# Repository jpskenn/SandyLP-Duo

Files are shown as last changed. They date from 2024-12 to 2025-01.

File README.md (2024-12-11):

# SandyLP Duo（サンディ エルピー デュオ）

![SandyLP Duo keyboard]()  

"SandyLP Duo" is a Split 40% keyboard with symmetrical row staggered layout and key height optimization.

Layered PCB will make height differences for each key.
This covers the lack of optimization to physical key layout in two dimensions that only adjust x-y plane.

---

SandyLP Duoは、スイッチの配置を立体的にして高さ方向への最適化を加えた、左右対称ロースタッガード配列の分割型40%キーボードです。  

平面上のキーレイアウトだけでは最適化しきれない部分を、キーの位置に応じてスイッチを配置する高さを変えることで補っています。

開発の元となった[SandyLP](https://github.com/jpskenn/SandyLP)の機能や特徴を踏襲しつつ、肩や腕を開いたより自然なポジションでの打鍵と、テンティングによる手首や腕の負荷軽減を目指しています。

SandyLPのコンセプトをそのまま引きついだバリエーションモデルとして、分割型の特徴である左右ふたつのペアを思わせる言葉の「Duo」を後ろにつけ、「SandyLP Duo」としました。  
元の元であるSandyから説明すると、スイッチを立体的（3D）に配置したキーボードの、ロープロファイル版、分割型バリエーションモデルということになります。

## 特徴

### 分割型

見てのとおり、右手用と左手用のふたつに分かれた、分割型キーボードです。
右手用または左手用のどちらかをPCやMacに接続し、もう一方へUSB Type-Cケーブルで接続します。

右手用と左手用を好みの場所に配置し、好みのポジションで打鍵できます。
前作の一体型キーボードSandyLP（中央部に2u分の間隔）に比べ、肩や腕を大きく開いたポジションをとることが可能で、肩や腕の負荷軽減が見込まれます。

また、ゴム足等を使ったテンティング（キーボードの内側を持ち上げて、親指側と小指側の高さを変える）をおこなうことで、手首や腕の負荷軽減が見込まれます。

### 左右対称のキーレイアウト  

[Jones](https://github.com/jpskenn/Jones)と同様の、2行目と3行目にずれのない、左右対称なシンメトリカル ロースタッガードのレイアウトです。  
左右対称のキーレイアウト

一般的なロースタッガードなレイアウトとの共通性を残しつつ、左右対称で打鍵しやすくなるよう、[SemiErgo Layout](https://github.com/mtei/SemiErgo_Layout)に準ずるキーマッピングで使用することを念頭に設計しています。  
Z行の左右端にシフトキーを用意していないので、スペースキーを「Space and Shift」として使うと便利です。

このレイアウトは、市販の各種キーキャップセットのうち「Base Kit」と呼ばれる基本的なキットですべてを埋めることができます。また、104キーの英語キーキャップセットでも十分実用が可能です。
〓Base Kitと104の検証
左右対称のキーレイアウト

詳しくは、[Keyboard Layout Editor: SandyLP Duo]()を参照してください。

### キースイッチを立体的に配置  

前機種の[Sandy](https://github.com/jpskenn/Sandy)と同じく、キースイッチを3段階の高さで立体的に配置しています。  
平面上ではキーを配置できる範囲が限られるため、一部のキーはどうしても指が届きにくくなってしまいます。例えば、[Jones](https://github.com/jpskenn/Jones)では左右対称のレイアウトを採用することで右手小指の`P`や`Back Space`、`Enter`などは打鍵しやすくなりましたが、右手人差し指の`Y`は少し遠く感じられました。  
このような箇所について、キーの配置を高くすることで打鍵しやすさを向上させています。  

キースイッチの高さ（中央部分）
キースイッチの高さ（横から）

キーの高さはLow（基準高＝0mm）, Middle（3.6mm）, High（8.7mm）の3段階で、以下のように配置されます。  
キーの高さ

### キーボード自体が低い（薄い）  

ロープロファイルの`Choc V2`スイッチを採用することでキーボード自体が低くなりました。  
前機種のSandyからは7.2mm（※1）低くなり、パームレストを使わずとも、手首をあまり反らさないポジションで打鍵できます。

※1 ボトムプレートから1段目のスイッチ軸の天面までの高さを比較。なお、Sandyは理論上あと0.8mm低くすることが可能です。

キースイッチの高さ

### RP2040を採用した構成により、多機能なファームウェアを使用可能

RP2040を採用した構成により、キーボード向けのファームウェアを格納するには十分すぎるほどのフラッシュ容量を得ることができました。  
エンコーダーやオーディオ、その他各種機能の同時有効化や、多数のレイヤーを使用するなど、多機能なファームウェアを使用可能です。

### Remap、Vialによるキー割り当ての変更  

初期書き込み済みのファームウェアは[Remap](https://remap-keys.app/)に対応しており、プログラミング等の知識がなくても、キーマッピングやロータリーエンコーダへの割り当てを、ブラウザ等を使って簡単に変更できます。  

また、Vial対応のファームウェアに書き換えて使用することもできます。

### オプション機能  

- ロータリーエンコーダ
- インジケータLED
- オーディオ

## ビルドガイド

## SNSタグ

[#SandyLP_Duo](https://twitter.com/search?q=%23SandyLP_Duo)

## ギャラリー

## 参考事例

## 開発経緯

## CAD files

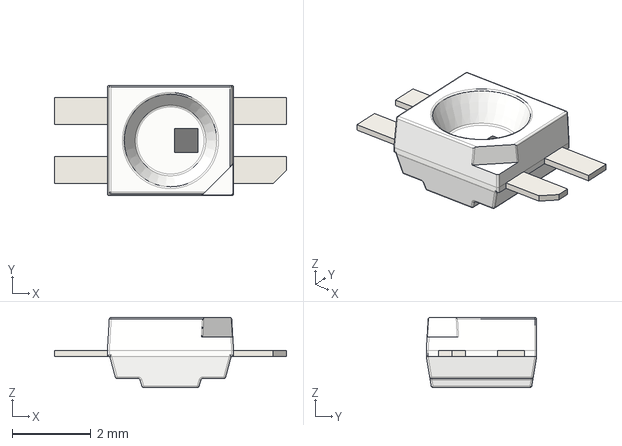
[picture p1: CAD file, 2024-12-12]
PCB/SandyLPD_Plate_BottomB/lib_LED/LED_SK6812MINI-E.step
5.88 x 2.80 x 1.78 mm

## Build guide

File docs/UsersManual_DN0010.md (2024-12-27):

# SandyLP Duo（DN0010）ユーザーズマニュアル

このドキュメントは、SandyLP Duo（DN0010）の組み立てや使用方法についてまとめたユーザーズマニュアルです。

組み立てや使用の前に[注意事項](#注意事項)をお読みください。

また、正しい使用方法の理解や各種トラブルの防止のため、早い時期に一通りお読みになることをお勧めします。

SandyLP Duoのコンセプトや特徴、ビルド例などについては、こちらの[README](https://github.com/jpskenn/SandyLP-Duo/blob/main/README.md)をご覧ください。

## 目次

<!-- @import "[TOC]" {cmd="toc" depthFrom=1 depthTo=3 orderedList=false} -->

<!-- code_chunk_output -->

- [SandyLP Duo（DN0010）ユーザーズマニュアル](#sandylp-duodn0010ユーザーズマニュアル)
  - [目次](#目次)
  - [注意事項](#注意事項)
  - [ビルドガイド](#ビルドガイド)
    - [部品リスト](#部品リスト)
    - [組み立てに使用する工具](#組み立てに使用する工具)
    - [組み立て手順](#組み立て手順)
  - [カスタマイズガイド](#カスタマイズガイド)
    - [初期ファームウェアの機能と設定値](#初期ファームウェアの機能と設定値)
    - [SandyLP Duo関連ファイル](#sandylp-duo関連ファイル)
    - [ファームウェアを書き換える](#ファームウェアを書き換える)
    - [EEPROMを消去して初期状態に戻す](#eepromを消去して初期状態に戻す)
    - [電源LEDを点灯しないようにする](#電源ledを点灯しないようにする)
    - [キーキャップの選び方](#キーキャップの選び方)
  - [サービスマニュアル](#サービスマニュアル)
    - [パーツリスト](#パーツリスト)
    - [基板セットアップ](#基板セットアップ)

<!-- /code_chunk_output -->

## 注意事項

〓TODO
〓ここには、基本的にクリティカルな何かだけ書くようにする。
〓場合によって、基板上のエラッタ的なものも記載。

## ビルドガイド

SandyLP Duo（DN0010）を組み立てる手順を説明します。

カッコ内の`DN0010`は開発番号を表しており、各基板のうら側に記載されています。  
<small>（外観上の理由により、リバーシブルのスイッチプレートには記載していません。）</small>
開発ナンバー

[組み立て手順](#組み立て手順)に一通り目を通してから作業を始めると、ミスの防止につながります。

### 部品リスト

このキーボードを組み立てて完成させるためには、[キット内容](#キット内容)に加え、[別途用意が必要な部品](#別途用意が必要な部品)が必要です。  

[オプション部品](#オプション部品)は無くても完成させることができます。  
使いたい機能に応じて用意してください。  

#### キット内容

このキットに同梱されている部品等の内容です。  

| 部品名 | 個数 | 備考 |
| :-- | :--: | :-- |
| ご案内リーフレット | 1 | |
| 基板Base（ひだり） | 1 | 多数の部品を取り付け済み。 |
| 基板Base（みぎ） | 1 | 多数の部品を取り付け済み。 |
| 基板Mid内側（ひだり・みぎ） | 2 | 同一形状の2枚を、左用、右用として使用。 |
| 基板Mid外側 （ひだり・みぎ）| 2 | 同一形状の2枚を、左用、右用として使用。 |
| 基板Top （ひだり・みぎ）| 2 | 同一形状の2枚を、左用、右用として使用。 |
| Base用スイッチプレート（ひだり・みぎ） | 2 | 同一形状の2枚を、左用、右用として使用。 |
| Mid内側用スイッチプレート（ひだり・みぎ） | 2 | 同一形状の2枚を、左用、右用として使用。|
| Mid外側用スイッチプレート（ひだり・みぎ） | 2 | 同一形状の2枚を、左用、右用として使用。 |
| Top用スイッチプレート（ひだり・みぎ） | 2 | 同一形状の2枚を、左用、右用として使用。 |
| ボトムプレートA | 2 | 〓未定 |
| ボトムプレートB | 2 | 同一形状の2枚を、左用、右用として使用。 |
| スペーサー<br>中空 M2 3.5mm | 6 | [CB-2003.5E](https://hirosugi.co.jp/products/B/CB-E.html#bx3) |
| 長いスルーホールタップ<br>M2 2mm | 22 | [THC-0.8-2.0-2](https://www.mac8sdk.co.jp/products/713) |
| 短いスルーホールタップ<br>M2 1mm | 22 | [THC-0.8-1.0-2](https://www.mac8sdk.co.jp/products/713) |
| 長いねじネジ<br>M2 8mm | 6 | [F-0280N-03](https://wilco.jp/products/F/F-N-03.html#page3) |
| 短いネジ<br>M2 3mm | 16 | [F-0230N-02](https://wilco.jp/products/F/F-N-02.html#page3) |
| 長いプラネジ<br>M2 5mm | 16 | [PC-0205](https://wilco.jp/products/PC/PC.html#page2) |
| 短いプラネジ<br>M2 3mm | 12 | [PC-0203](https://wilco.jp/products/PC/PC.html#page2) |
| ゴム足 | 4 | 〓半球っぽいやつにしたい |
| USBコネクタキャップ | 1 | 出荷時は`基板Base（みぎ）`へ取り付け済み。[TK-CAP6W](https://www.yodobashi.com/product/100000001003693842/) |
| ダイオード<br>1N4148W SOD123 | 15 | 予備3個含む。<br>[1N4148W](https://akizukidenshi.com/catalog/g/g107084/) |
| LED<br>WS2812C-2020 | 6 | [WS2812C-2020](https://akizukidenshi.com/catalog/g/g115068/) |
| Chocスイッチ用ソケット | 50 | 予備4個含む。<br>[Kailh Switch Socket（Kailh Choc ロープロファイル用）](https://shop.yushakobo.jp/products/a01ps?variant=37665172553889) |
| ゴムシート<br>T=1mm 10mm * 500mm | 〓使用本数未定 | [低弾性ゴムシート－ハネナイトＲ](https://jp.misumi-ec.com/vona2/detail/110300277050/?ProductCode=UNLEA1-10) |
| ポロンシート<br>T=1.5mm 50mm * 〓50mm幅で何mm | 1 | [イノアック L32-1.550-MT マイクロセルウレタンロールPORON 黒 1.5×50mm×1M巻](https://www.yodobashi.com/product/100000001004002516/) |

※備考欄には入手性のよい製品を記載しています。出荷時期によって機能的に同等なものへ変更することがあります。

基板  
〓左上から時計回りに、基板Top、基板Mid中央、基板Mid左右（2枚）、基板Base。  
〓基板  

プレート類  
〓左上から時計回りに、Top用スイッチプレート、Mid中央用スイッチプレート、Mid左右用スイッチプレート（2枚）、Base用スイッチプレート、ボトムプレート。  
〓プレート類  

〓その他部品  
〓その他部品  
〓ネジとかは乗せなくても良いけど、ゴムシートは見分けがつきにくいので、写真を載せる。

#### 別途用意が必要な部品

完成させるには、キット内容とは別に、以下の部品を用意する必要があります。

| 部品名 | 個数 | 備考 |
| :-- | :--: | :-- |
| Choc V2スイッチ | 46 | ロータリーエンコーダを取り付ける場合は、その分だけスイッチの取り付け数が減ります。<br>Choc V1スイッチは、固定ピンがないもの、または固定ピンを取り外したものであれば取り付け可能です。<br>ピンが折れたりした場合に備えて少し多めに買っておくとよいでしょう。 |
| キーキャップ<br>Choc V2スイッチ用 | 必要数 | GMKやePBT等のいわゆるBase Kitを使用すると、良い具合に仕上げることが可能です。<br>一部のMXスイッチ用のキーキャップは、組み合わせによってはスイッチプレートやスイッチに干渉する場合があります。<br>詳しくは[キーキャップの選び方](#キーキャップの選び方)を参照してください。 |
| USBケーブル （Type-C） | 1 | コンピュータ等への接続に使用します。Type-C to Type-Cや、Type-C to Type-Aなどを用意してください。<br>Base基板に取り付けられているコネクタはType-Cです。 |
| USBケーブル （Type-C to Type-C） | 1 | 左右のデバイス間通信に使用します。 |

#### オプション部品

オプション部品は無くてもかまいません。  
使いたい機能に応じて用意します。

| 部品名 | 個数 | 備考 |
| :-- | :--: | :-- |
| DIPスイッチ | 2 | [表面実装DIPスイッチ 4P](https://akizukidenshi.com/catalog/g/g108929/) |
| ロータリーエンコーダ<br>ALPS EC11, EC12同等品 | 1 | ロータリーエンコーダを使用する場合。<br>プッシュスイッチ付きにも対応。 |
| ロータリーエンコーダ用ノブ（つまみ） | 1 | ロータリーエンコーダを使用する場合。 |
| スピーカー<br>Murata PKMCS0909E4000-R1 | 〓2 | [PKMCS0909E4000-R1](https://www.digikey.jp/ja/products/detail/murata-electronics/PKMCS0909E4000-R1/4878400) |

### 組み立てに使用する工具

こちらの[工具セット](https://shop.yushakobo.jp/products/a9900to)などを参考に工具を用意します。

- 必要な工具

  - 先の細いプラスドライバー

    M2ネジに対応する「#0」など。

  - はんだ付け関連用品

    はんだ、はんだごて（温度調整機能つきを推奨）、こて台、ピンセットなど。  
    小さな部品のはんだ付けや、ちょっとした修正、取り外しなどの作業がしやすくなるので、フラックスやハンダ吸い取り線もあると良いでしょう。

  - はさみ または カッター
    ゴムシートの切断に使用。

- あると便利な工具

  - マジックペン

    基板の側面を塗ると、完成時の質感が上がります。  
    暗めの色を塗る場合は[プロッキー](https://www.mpuni.co.jp/products/felt_tip_pens/water_based/sign_pen/prockey.html)を、明るめの色を塗る場合は不透明顔料インクの[ポスカ](https://www.mpuni.co.jp/products/felt_tip_pens/water_based/posca/standard.html)を使うなど、お好みで。

  - テスター  
    はんだ付けの確認作業や、何か不具合があった場合の原因調査で活躍します。

### 組み立て手順

手順に沿って、順番に組み立てます。

- 【こだわり作業】の手順は、完成時の質感を重視した内容であり、不要であれば作業をとばしてもかまいせん。

- 【該当者のみ】の手順は、条件に該当する場合のみ作業します。

- みぎ側とひだり側、おもて側とうら側を間違えないよう、基板の表記を確認しながら作業を進めます。

    左右の表記  
    左右の表記

    うら側の表記  
    Back Sideの表記

#### 組み立て前の確認

出荷前に基本的な動作確認を実施済みですが、輸送時の破損なども考えられるため、組み立てを始める前に動作確認をおこないます。  
確認結果に問題がある場合は、リーフレットに記載の連絡先へ相談してください。

##### 基板BaseがPCやMacで認識されるかを確認する

1. `基板Base（ひだり）`を用意し、基板のうら側を上にして安定した場所へ置く。

1. `Computer`と書かれたUSBコネクタへケーブルを差し込み、PCやMacに接続する。

1. 基板うら側の電源LED〓`STLED`が緑色に点灯することを確認する。

1. PCやMacで、キーボードとして認識されていることを確認する。  
    確認例：
    - Windows 11  
    設定 → Bluetoothとデバイス → デバイス → 入力  
    「sandy_lpd」が表示されていること。

    - Mac  
    システムレポート → USB  
    「sandy_lpd」が表示されていること。

1. 確認出来たら、USBケーブルを抜く。

1. `基板Base（みぎ）`についても、同様の確認をおこなう。

    💡ヒント：出荷時は`基板Base（みぎ）`の`Computer`と書かれたUSBコネクタにキャップが取り付けられています。キャップを外して確認します。  

1. USBコネクタにキャップを取り付ける。

    確認が終わったら、普段使わない方の`Computer`と書かれたUSBコネクタにキャップを取り付け、誤って同時接続しないようにします。

##### 基板Baseの反応を確認する

1. `基板Base（ひだり）`と`基板Base（みぎ）`を用意し、それぞれの基板の`Keyboard`と書かれたUSBコネクタへケーブルを差し込み、左右を接続します。

1. 左右いずれかの`Computer`と書かれたUSBコネクタへケーブルを差し込み、PCやMacに接続します。

    左右の基板うら側の電源LEDが緑色に点灯することを確認する。

1. [Remap（https://remap-keys.app/）](https://remap-keys.app/)を、対応するブラウザ（ChromeやEdgeなど）で開く。

1. `CUSTOMIZE YOUR KEYBOARD`ボタンを押す。

1. `+ KEYBOARD`を押す。

1. ポップアップ画面で`sandy_lpd`を選択して、`接続`を押す。  

1. 画面にキーボードのレイアウトが表示されるまでしばらく待つ。

    30秒待っても表示されないときは、ブラウザをリロードしてやり直します。

1. キーボードのレイアウトの右側の一番下にある`…`をクリックして、表示されたメニューから`Test Matrix Mode`を選択する。

1. キースイッチの反応を確認する。

    基板うら側のスイッチソケット取り付け用パッド（銀色の四角い端子部分）をピンセットなどでショートさせ、ブラウザ画面上の対応するキーの色が変わることを確認します。

    スイッチ取り付け用パッド

    すべてのパッドで実施した後、以下のように色が変われば正常です。  
    基板Base確認結果

#### 【こだわり作業】基板とスイッチプレート側面をマジックで塗る

完成時の質感を高めるため、すべての基板とスイッチプレート、ボトムプレートの側面をマジックで塗ります。

💡ヒント：組み立て後は、スイッチを取り外したりネジを外して分解したりしないと塗れなくなる箇所があります。後からやるのは大変なので、どうせなら、この段階でやってしまった方が楽です。

#### 部品のはんだ付け

##### 基板Topへのはんだ付け

1. `基板Top（ひだり・みぎ）`の2枚を、うら側が見えるように置く。

    片方は「Left 左 Back Side」、もう片方は「Right 右 Back Side」と書かれた面が見えるようにします。

1. うら側から、`ダイオード`を取り付ける。（左右それぞれ1個）

    `基板Top（ひだり）`は`D1`へ、  
    `基板Top（みぎ）`は`D2`へ取り付けます。  〓Dの番号？
    取り付け位置

    基板のダイオード用パッド2個のうち、片方のパッドに予備はんだ（はんだを少しだけつけておく）します。  
    基板に描かれた枠のうち、短辺が閉じている方向（▲マークが示す先の少し太い線がある方向）にダイオードの印を合わせ、予備はんだしたところへ、ダイオードの端子をはんだ付けします。  
    片方を固定できたら、もう一方の端子をはんだ付けします。  
    ダイオードの方向

1. うら側から、`Chocスイッチ用ソケット`を取り付ける。（左右それぞれ1個）

    基板に描かれた枠に合わせてソケットを置きます。  

    💡ヒント：Chocスイッチ用ソケットは、取り付ける方向が決まっています。参考：[Kailh Choc ソケットの方向について](https://scrapbox.io/self-made-kbds-ja/Kailh_Choc_ソケットの方向について)

    Chocスイッチ用ソケットの方向

    ダイオードを取り付けた時と同様に、片方のパッドに予備はんだして取り付けます。
    ソケットが基板にぴったりと接するように、プラ部分をピンセットで押さえながらはんだ付けするとよいでしょう。

    取り付け位置

1. `基板Top（ひだり・みぎ）`の2枚を、おもて側が見えるように置く。

    先ほど取り付けた部品が下側になるように、基板をひっくり返します。

1. おもて側から、`短いスルーホールタップ`を取り付ける。（左右それぞれ2個）

    `基板Top（ひだり）`は`〓`へ、  
    `基板Top（みぎ）`は`〓`へ取り付けます。

##### 基板Mid内側へのはんだ付け

1. `基板Mid内側（ひだり・みぎ）`の2枚を、うら側が見えるように置く。

    片方は「Left 左 Back Side」、もう片方は「Right 右 Back Side」と書かれた面が見えるようにします。

1. うら側から、`ダイオード`を取り付ける。（左右それぞれ3個）

    `基板Top（ひだり）`は`D1`...`D3`へ、  
    `基板Top（みぎ）`は`D4`...`D6`へ取り付けます。  〓Dの番号？  
    取り付け位置

1. うら側から、`Chocスイッチ用ソケット`を取り付ける。（左右それぞれ3個）

    取り付け位置

1. `基板Mid内側（ひだり・みぎ）`の2枚を、おもて側が見えるように置く。

1. おもて側から、`短いスルーホールタップ`を取り付ける。（左右それぞれ2個）

    `基板Top（ひだり）`は`D1`...`D3`へ、  
    `基板Top（みぎ）`は`D4`...`D6`へ取り付けます。  〓Holeの番号？  

##### 基板Mid左右へのはんだ付け

1. `基板Mid外側（ひだり・みぎ）`の2枚を、うら側が見えるように置く。

    片方は「Left 左 Back Side」、もう片方は「Right 右 Back Side」と書かれた面が見えるようにします。

1. うら側から、`ダイオード`を取り付ける。（左右それぞれ2個）

    `基板Top（ひだり）`は`D1`...`D3`へ、  
    `基板Top（みぎ）`は`D4`...`D6`へ取り付けます。  〓Dの番号？  
    取り付け位置

    取り付け位置

1. うら側から、`Chocスイッチ用ソケット`を取り付ける。（左右それぞれ2個）

    取り付け位置

    取り付け位置

1. `基板Mid外側（ひだり・みぎ）`の2枚を、おもて側が見えるように置く。

1. おもて側から、`短いスルーホールタップ`を取り付ける。（左右それぞれ2個）

    `基板Top（ひだり）`は`D1`...`D3`へ、  
    `基板Top（みぎ）`は`D4`...`D6`へ取り付けます。  〓Holeの番号？

##### 基板Baseへのはんだ付け

1. `基板Base（みぎ・ひだり）`を、うら側の「Back Side」と書かれた面が見えるように置く。

1. うら側から、`Chocスイッチ用ソケット`を取り付ける。（左右それぞれ23個）

    ロータリーエンコーダを取り付ける場合は、ソケットは取り付けません。

    取り付け位置

1. 【該当者のみ】うら側から、`スピーカー`を取り付ける。

    条件：スピーカーを使用する場合

    `基板Top（ひだり）`は`LS1`へ、  
    `基板Top（みぎ）`は`LS2`へ取り付けます。

    スピーカー取り付け位置

    スピーカーの左右にある金属端子部分を基板上のパッドに合わせてスピーカーを置き、スピーカー側面からはんだ付けします。  
    電気的な極性はないので、左右どちらの方向に取り付けてかまいません。

1. うら側から、`短いスルーホールタップ`を取り付ける。（左右それぞれ3個）

    **☠️危険：この手順のみ、うら側からスルーホールタップを取り付けます。**

    `基板Top（ひだり）`は`D1`...`D3`へ、  
    `基板Top（みぎ）`は`D4`...`D6`へ取り付けます。  〓Holeの番号？

1. `基板Base（ひだり・みぎ）`の2枚を、おもて側が見えるように置く。

1. 【該当者のみ】おもて側から、`LED`を取り付ける。（左右それぞれ3個）

    条件：インジケータLEDを使用する場合

    `基板Top（ひだり）`は`L1`...`L3`へ、  
    `基板Top（みぎ）`は`L4`...`L6`へ取り付けます。  〓番号？  

    取り付け位置

    LED取り付け用パッド（1個のLEDに4個のパッド）のひとつに、予備はんだしておきます。  
    基板に描かれた印にLEDの端子の切り欠き部分を合わせ、LED発光部が基板おもて側になるように置きます。  〓LEDの指標？

    LED取り付けマーキング

    予備はんだした箇所を、少し低い温度の220度程度ではんだ付けします。  
    （はんだが溶けにくい場合は、270度程度まで温度を上げ、短時間で作業します。）

    残りのパッドをはんだ付けします。

    LEDの取り付けが終わったら、USBケーブルでPCやMacに接続し、LEDがすべて白色に点灯することを確認します。  
    （ケーブル接続時に一瞬だけ赤色に点灯する場合がありますが、正常な動作です。）

1. 【該当者のみ】おもて側から、`ロータリーエンコーダ`を取り付ける。（左右それぞれ1個）

    条件：ロータリーエンコーダを使用する場合

    **☠️危険：ロータリーエンコーダは「おもて側」からはめ込んで、うら側からはんだ付けします。**

    `基板Top（ひだり）`は`RE1`へ、  
    `基板Top（みぎ）`は`RE2`へ取り付けます。  〓番号？  

    取り付け位置

1. おもて側から、`長いスルーホールタップ`を取り付ける。（左右それぞれ4個〓個数合ってる？）

    **☠️危険：この手順のみ、`長いスルーホールタップ`を使用します。**

    `基板Top（ひだり）`は`D1`...`D3`へ、  
    `基板Top（みぎ）`は`D4`...`D6`へ取り付けます。  〓Holeの番号？
〓ここから
#### 基板へのネジ止めとゴムシート貼り

**☠️危険：ネジを締めこむ際は、少し抵抗を感じて「クククッ」と止まったあたりで締めこむのをやめます。**
**「ギュゥギュゥ」と締めこみすぎると、そのうち基板が物理的に破壊されます。**

💡ヒント：ネジ穴の隣には、その場所に取り付ける「ネジ」や「スペーサー」などのアイコンが描かれています。  
ネジ穴の印  

##### 基板Top（ひだり・みぎ）へのゴムシート貼り

1. 基板のうら側から、`ゴムシート`を貼る。（6個）

    〓シルクで貼り付け位置を描くつもり

    各種パーツやネジ穴に重ならない位置へ、フォームを貼ります。  
    少し曲げたり、一部をカットしてから貼ってもかまいません。

    貼り付け例  
    貼り付け位置

##### 基板Mid中央へのネジ止めとゴムシート貼り

1. `基板Mid中央`のうら側から、`ワッシャー`を挟んだ`スペーサー`を`短いネジ（3mm）`でとめる。（4箇所）

    ```text
    スペーサー
    ↑
    ワッシャー  
    ↑
    －－ 基板Mid中央 －－
    ↑
    短いネジ（3mm）
    ```

    基板Mid中央 うら側ネジ止め箇所

1. おもて側から、`ワッシャー`を挟んだ`ナット`を`長いネジ`でとめる。（8箇所）

    ```text
    長いネジ（6mm）
    ↓  
    －－ 基板Mid中央 －－  
    ↓  
    ワッシャー  
    ↓  
    ナット
    ```

    基板Mid中央 おもて側ネジ止め箇所

1. うら側の空いたスペースに`細くて薄いゴムシート`を貼る。

    **☠️異なる厚さのゴムシートを貼ると、正しく組み立てられません。**

    防振と打鍵感向上のため、各種パーツやネジ穴に重ならない位置へ、ゴムシートをはさみなどで切断して貼ります。  
    貼り付け位置は、以下のとおりです。

    ゴムシート貼り付け位置  
    貼り付け位置

##### 基板Mid左右へのネジ止めとゴムシート貼り

1. `基板Mid左右`のおもて側から、`ワッシャー`を挟んだ`ナット`を`長いネジ`でとめる。（左右それぞれ4箇所、計8箇所）

    **☠️危険：中央部分のネジ穴と隣のソケット用パッドが近いので、ワッシャーをなるべくパッドから離すような気持ちで取り付ける。**

    ```text
    長いネジ（6mm）
    ↓  
    －－ 基板Mid左右 －－  
    ↓  
    ワッシャー  
    ↓  
    ナット
    ```

    基板Mid左右 おもて側ネジ止め箇所

    基板Mid左右 おもて側ネジ止め箇所

1. うら側の空いたスペースに`細くて薄いゴムシート`を貼る。

    **☠️危険：異なる厚さのゴムシートを貼ると、正しく組み立てられません。**

    ゴムシート貼り付け位置  
    貼り付け位置

##### 基板Baseへのネジ止めとゴムシート貼り

1. `基板Base`のおもて側から、`スペーサー`を`短いネジ（2mm）`でとめる。11箇所）

    **☠️危険：この手順のみ`短いネジ（2mm）`を使用します。**

    ```text
    短いネジ（2mm）
    ↓  
    －－ 基板Base －－  
    ↓  
    スペーサー
    ```

    基板Bass おもて側ネジ止め箇所

1. うら側から、`ワッシャー`を挟んだ`ナット`を`長いネジ`でとめる。（2箇所）

      ```text
      ナット
      ↑
      ワッシャー  
      ↑
      －－ 基板Base －－  
      ↑
      長いネジ（6mm）  
      ```

    基板Baseうら側ネジ止め箇所（長いネジ）

1. うら側から、`細くて分厚いゴムシート`を貼る。

    **☠️危険：異なる厚さのゴムシートを貼ると、正しく組み立てられません。**

    ゴムシート貼り付け位置  
    貼り付け位置

#### スイッチプレートへのゴムシート貼り

**☠️危険：異なる厚さのゴムシートを貼ると、正しく組み立てられません。**

`すべてのスイッチプレート`の裏面に`太くて薄いゴムシート`を貼ります。  
スイッチプレートの細い箇所には、ゴムシートを半分、または1/3の幅に切断してから貼るようにします。  
貼り付け位置は、以下のとおりです。

ゴムシート貼り付け位置  
Base用スイッチプレート  
貼り付け位置

Mid中央用スイッチプレート  
貼り付け位置

Mid左右用スイッチプレート  
貼り付け位置

Top用スイッチプレート  
貼り付け位置

【こだわり作業】`Base用スイッチプレート`うら側のLED穴へ、`プラ板（乳白）`を両面テープで貼り付けます。

#### 基板とスイッチプレートをひとつに組み合わせて、スイッチを取り付ける

**☠️危険：ネジやナットを締めこむ際は、少し抵抗を感じて「クククッ」と止まったあたりで締めこむのをやめます。**

1. `基板Base`と`基板Mid中央`を組み合わせる。

    それぞれのネジ穴にはまるように重ね合わせます。  

    `基板Base`のうら側から、`基板Mid中央`のネジを`ナット`で止めます。（8箇所）

    ```text
    －－ 基板Mid中央 －－  
    ↓  
    －－ 基板Base －－  
    ↑  
    ナット
    ```

    基板Bass うら側ナット止め箇所

    `基板Mid中央`のおもて側から、`スペーサー`を取り付けます。（2箇所）

    ```text
    スペーサー
    ↓
    －－ 基板Mid中央 －－  
    ↑  
    －－ 基板Base －－  
    ```

    基板Mid中央 おもて側スペーサー取り付け箇所

1. `基板Base`と`基板Mid左右`を組み合わせる。

    ネジ穴にはまるように重ね合わせます。  

    `基板Base`のうら側から、`基板Mid左右`のネジを`ナット`で止めます。（ぞれぞれ4箇所、計8箇所）

    **☠️危険：1箇所、ナット付近に小さなパーツが配置されているところがあります。レンチ等が小さなパーツに当たらないようにします。**

    ```text
    －－ 基板Mid左右 －－
    ↓
    －－ 基板Base －－
    ↑
    ナット
    ```

    基板Bass うら側ナット止め箇所

1. `Mid中央用スイッチプレート`とスイッチを取り付ける。

    スイッチの端子が曲がっていないことを確認します。  
    スイッチプレートを基板の形に合わせて重ねます。  
    スイッチの端子と基板のソケットの方向を確認します。  
    スイッチプレートを挟みながら、スイッチをまっすぐに押し込んで取り付けます。  

    メモ：  
    スイッチによっては、スイッチプレートへのはめ込みがきついものがあります。  
    Kailh Lofree FLOW GHOSTはけっこうきつく、Kailh Deep Sea Silent MINIは適度な具合でした。

    ```text
    －－ スイッチ －－
    ↓
    －－ Mid中央用スイッチプレート －－
    ↓
    －－ Mid中央基板 －－
    ```

    スイッチがプレートにぴったりとはまっていることを確認します。  

    以下の写真はスイッチがプレートにはまっておらず、プレートが押し下げられた不正な状態です。  
    プレートの端を指で持ち上げたりして、スイッチをプレートにぴったりとはめ込みます。  
    スイッチがプレートから浮いている不正な状態

1. `基板Top`と`基板Mid中央`を組み合わせる。

    間に`Mid中央用スイッチプレート`をはさむようにして、ネジ穴にはまるように重ね合わせます。  

    `基板Top`のおもて側から、`基板Mid中央`のスペーサーを`短いネジ（3mm）`で止めます（6箇所）

    ```text
    短いネジ（3mm）
    ↓  
    －－ 基板Top －－
    ↑  
    －－ 基板Mid中央 －－
    ```

1. `基板Base`に、`Base用スイッチプレート`と`スイッチ`を取り付ける。

    💡ヒント：`Base用スイッチプレート`は、ロゴ入りのおもて面と、無地のうら面のどちら向きでも使えるリバーシブル仕様です。  
    キーキャップを取り付けるとプレートに書かれた文字はほとんど見えなくなりますが、小さ目のキーキャップを使う場合は少し目立ってしまうかもしれません。

    ```text
    スイッチ
    ↓
    －－ Base用スイッチプレート －－
    ↓
    －－ Base基板 －－
    ```

1. `基板Mid左右`に、`Mid左右用スイッチプレート`と`スイッチ`を取り付ける。

    ```text
    スイッチ
    ↓
    －－ Mid左右用スイッチプレート －－
    ↓
    －－ Mid基板 －－
    ```

1. `基板Top`に、`Top用スイッチプレート`と`スイッチ`を取り付ける。

    ```text
    スイッチ
    ↓
    －－ Top用スイッチプレート －－
    ↓
    －－ Top基板 －－
    ```

#### 動作確認する

1. [Remap](https://remap-keys.app/)の`Test Matrix Mode`を使用して、すべてのキースイッチが正常に反応するか確認する。

    異常がある場合は、原因を調査して修正します。

#### ボトムプレートを取り付ける

1. 組み合わせた基板を裏返し、USBコネクタの切り欠き部分の位置を合わせながら`ボトムプレート`を乗せる。

1. `ボトムプレート`うら側から、`短いネジ（3mm）`で止める。（11箇所）

    ```text
    －－ 組み合わせた基板 －－
    ↓  
    －－ ボトムプレート －－
    ↑
    短いネジ（3mm）
    ```

    ボトムプレートうら側からのネジ止め箇所

1. ボトムプレートのうら側から、ゴム足を貼る。

#### キーキャップを取り付ける

1. `キーキャップ`を取り付ける。

1. 【該当者のみ】`ロータリーエンコーダ`の`ノブ`を取り付ける。

    条件：ロータリーエンコーダを使用する場合

以上で組み立て完了です。
完成

## カスタマイズガイド

SandyLP Duoの機能や関連情報、また、自分の好みにカスタマイズする方法について説明します。

### 初期ファームウェアの機能と設定値

出荷時に書き込まれている初期ファームウェアの機能と設定値を説明します。

- QMKバージョン

  0.26.3

- キーマップ書き換えツールのRemapに対応（VIA有効化）。

- レイヤー構成とレイヤーインジケータLEDの色

  レイヤー0から7まで、8個のレイヤーが使用できます。  
  LEDは左右とも同じパターンで点灯します。`－`は元のレイヤー色、`×`は消灯を意味します。

    | No. | レイヤー名 | 主なキー割り当て | LEDの色 上, 中, 下 |
    | :-: | :-- | :-- | :-: |
    | 0 | ベースレイヤー #1 | [SemiErgo](https://github.com/mtei/SemiErgo_Layout)風 英語配列, Mac向けモディファイア | 白, 白, 白 |
    | 1 | ベースレイヤー #2 | ↑ | 青, 青, 青 |
    | 2 | ベースレイヤー #3 | テンキー | 黄, 黄, 黄 |
    | 3 | Lower #1 | ファンクションキー<br>記号<br>音量コントロール | －, 緑, － |
    | 4 | Lower #2 | ↑ | －, 黄緑, － |
    | 5 | Raise #1 | 数字行<br>記号<br>カーソル移動 | －, 水, － |
    | 6 | Raise #2 | ↑ | －, 紫, － |
    | 7 | Adjust | ベースレイヤー切り替え<br>LED、Audio等の設定<br>スクロールロックなど | －, 赤, － |
    | 番外| CapsLock | n/a | －, －, 赤紫 |

- ハードウェア機能

  - ロータリーエンコーダ
    プッシュボタン付き1個に対応。

  - スピーカー
    スピーカー1個に対応。

- その他

  - デフォルトレイヤーの変更はEEPROMに保存されます
    `DF(0)`、`DF(1)`、`DF(2)`を使ったデフォルトレイヤーの変更はEEPROMに保存され、キーボードの電源が失われても変更したレイヤーで起動します。

  - キーボードの起動音（＝スピーカー機能）をON/OFFする

    `AdjustレイヤーのZ`を押すごとに、ON/OFFが切り替わります。  
    この操作により、スピーカー機能自体がON/OFFされるので、ピコピコ音や音楽鍵盤機能もOFFになります。

  - キー押下時のピコピコ音をON/OFFする

    `AdjustレイヤーのX`を押すごとに、ON/OFFが切り替わります。  
    なお、キーボードの起動音（＝スピーカー機能）がOFFになっているときは、ピコピコ音は鳴りません。

  - レイヤーインジケータの表示状態を切り替える

    レイヤーインジケータの表示状態は、以下の4通りの表示に切り替えることができます。

    - 左右両方に表示
    - 左のみ表示
    - 右のみ表示
    - インジケータ表示なし

    表示状態は`AdjustレイヤーのO（オー）`を押すごとに切り替わり、表示状態はEEPROMに保存されます。

    なお、インジケータ表示がない場所には、QMKの[RGB Lighting](https://docs.qmk.fm/features/rgblight)が表示されます。  
    LEDを完全に消灯するには、`AdjustレイヤーのL`を押して、RGB LightingをOFFにします。

  - レイヤーインジケータの明るさを調整する

    レイヤーインジケータの明るさは、RGB Lightingの明るさに連動しています。

    明るさを調整するには、  
    （RGB LightingがOFFのときは、`AdjustレイヤーのL`を押してONにしてから）
    `AdjustレイヤーのI`または`K`で明るさを調整します。

    調整が終われば、もういちど`AdjustレイヤーのL`を押してRGB LightingをOFFにしてもかまいません。

### SandyLP Duo関連ファイル

このキーボードに関連するファイルです。  

- ビルド済みファームウェア（QMK バージョン 0.26.3）： [sandy_lp_remap.uf2](../Firmware/sandy_lp_remap.uf2)

- ビルド済みファームウェア（Vial bb7961c）： [sandy_lp_vial.uf2](../Firmware/sandy_lp_vial.uf2)

- ファームウェアのソース

    私がQMKからフォークしたリポジトリ[https://github.com/jpskenn/qmk_firmware](https://github.com/jpskenn/qmk_firmware)の、[develop_SandyLP Duo_QMK_0.26.3](https://github.com/jpskenn/qmk_firmware/tree/develop_SandyLP Duo_QMK_0.26.3)ブランチ内、`keyboards/sandy_lp/`に配置しています。  

    また、Vial版については、私がvial-qmkからフォークしたリポジトリ[https://github.com/jpskenn/vial-qmk/](https://github.com/jpskenn/vial-qmk/)の、[develop_local](https://github.com/jpskenn/vial-qmk/tree/develop_local)ブランチ内、`keyboards/sandy_lp/`に配置しています。

- 基板等の設計ファイルやドキュメント、Remapの定義ファイルなど

    [SandyLP Duoリポジトリ](https://github.com/jpskenn/SandyLP Duo)のリリース[DN0010](https://github.com/jpskenn/SandyLP Duo/releases/tag/DN0010-001)にまとめてあります。

### ファームウェアを書き換える

**☠️危険：作業に失敗するとキーボードが機能しなくなることがあります。内容を理解した上で、自己責任でおこなってください。**

1. 以下の操作をおこない、SandyLP DuoをマスストレージデバイスとしてPCやMacに認識させます。

    1. USBケーブルが接続されている場合は、ケーブルを抜く。
    1. キーボードうら側の`SW1`ボタン（文字が見えにくいので写真を参照）を押したまま、USBケーブルを差し込む。  
        ケーブルを差し込んだら、ボタンから手を離す。  
    BOOTSELボタン
    1. PCやMacで、マスストレージの`RPI-RP2`として接続・認識されているか確認する。

1. 書き込みたいファームウェアのUF2ファイル（example.uf2）を、先ほどの`RPI-RP2`へコピー＆ペーストなどの操作で保存します。

以上で書き込み作業は完了です。  

UF2ファイルを保存すると、勝手に（自動的に）マスストレージの接続が解除され、キーボードとして起動します。  
Macでは「ディスクの不正な取り出し」に関するメッセージが表示されますが、特に問題ないので無視してかまいません。（Windowsは知りません）

### EEPROMを消去して初期状態に戻す

EEPROMに記録されているデータを消去し、初期状態に戻す方法について説明します。  

キーマップやLEDの表示モードなどのEEPROMに記録されているデータを消去し、初期状態に戻すことができます。  

1. USBケーブルを接続している場合は、ケーブルを抜きます。

1. キーボードの左上のキーを押したまま、USBケーブルを差し込みます。

1. ケーブルを差し込んで、1、2と数えてから、キーを押していた指を離します。
    キーボードが、PCやMacでマスストレージデバイスとして認識されます。

1. 5秒ほど待ってから、USBケーブルを抜きます。

1. USBケーブルを差し込みます。
    キーボードが起動します。

以上の操作でEEPROMが消去され、初期状態に戻ります。

### 電源LEDを点灯しないようにする

`基板Base`うら側の電源LEDは、ファームウェアの動作状況に関わらず、USBコネクタからの電源によって点灯しています。

電源LEDを点灯しないようにするには、次の手順をおこないます。  

1. `基板Base`うら側、`STLED`がはんだでジャンパされ、2つのパッドがつながった状態になっています。  
1. はんだごてを軽く当ててはんだを一部取り除き、つながっていない状態にします。

電源LEDを点灯させる場合は、`STLED`をはんだでジャンパして、つながった状態にします。

### キーキャップの選び方

このキーボードで使用するChoc V2スイッチには、十字形状の穴をもつ、いわゆるCherry MXに互換性のあるキーキャップ（以降、MX用キーキャップと言う）を取り付けることができます。  

#### キーキャップセット

GMKやePBT等のいわゆるBase Kitを使用すると、見た目的にも質感的にも良い具合に仕上げることが可能です。  
また、英語104キーのセットでもそれなりに使える感じに仕上がります。

キーキャップガイド

#### キーキャップとスイッチの組み合わせ

Choc V2などのロープロファイルなスイッチに合わせて設計されていないMX用キーキャップは、押下時にスイッチやスイッチプレートに当たり、干渉してしまうことがあります。  
また、Choc V2スイッチは販売時期やシリーズによってトップハウジングの形状が異なっているため、干渉を避けるにはキーキャップとスイッチの組み合わせが重要となります。

組み合わせについては、74thさんの「[Kailh x Lofree Shadowシリーズ、Kailh Choc V2(Deep Sea Silent MINI)で使えるキーキャップを調査した](https://74th.hateblo.jp/entry/chocv2-compatible-keycap)」や、以下の私自身が実際に試した結果を参考にしてください。（干渉しないことを保証するものではありません）

私が試した組み合わせ結果

| スイッチ | キーキャップ | 干渉の有無 | 使用感 |
| :-- | :-- | :-- | :-- |
| Kailh Lofree FLOW GHOST | ePBT, Cherry, Less But Better | プレート干渉はほぼなし。スイッチに当たっている感じがある。 | スイッチ自体の底打ち衝撃と干渉の音が若干ズレるような感じがあり、あまり気持ちよくない。 |
| Kailh Lofree FLOW GHOST | ENJOYPBT DOUBLESHOT ABS, Cherry, Dolch Yellow | プレート干渉あり。スイッチ干渉不明（スイッチに当たる前にプレートに当たっている） |  |
| Kailh Lofree FLOW GHOST | Keyreative, KAT, Space Cadet | プレート干渉なし。スイッチ干渉あり。 | スイッチには干渉しているが、スイッチ自体の底打ち衝撃と干渉の音が一体化しているためあまり気にならず、普通に使える。ePBT Cherryとは感触が異なる。 |
| Kailh Lofree FLOW GHOST | Signature Plastics, G20, individual | プレート干渉なし。スイッチ干渉あり。 | スイッチには干渉しているが、スイッチ自体の底打ちと一体化している。使えないこともない。 |
| Kailh Lofree FLOW GHOST | NuPhy, nSA, BOW | 干渉なし。 |  |
| Kailh Deep Sea Silent MINI | Signature Plastics, DSS, Solarized Dark | プレートへのクリアランスはぎりぎりで、数個のキーで干渉あり（個体差？）。スイッチ干渉なし。 | 一部気になるところがあるが、基本的には問題なし。日常的に使用中。 |
| Kailh Deep Sea Silent MINI | Signature Plastics, G20, individual | プレート干渉なし。スイッチ干渉あり。 | 押下時コツコツという小さい音と感触があり、サイレントではなくなる。 |
| Kailh Deep Sea Silent MINI | ePBT, Cherry, EPBT x Openkey Less but better | 干渉なし。 | 50個に1個くらいの割合でキーキャップと干渉するスイッチがある（内部のダンパーがずれている？）ので、スイッチを5個くらい多めに買っておいて選別するとよい。日常的に使用中。 |

キースイッチとキースイッチの組み合わせ

## サービスマニュアル

基板の出荷準備作業などについてのメモ。

### パーツリスト

| 部品 | 個数 | 備考 |
| :---- | :-----: | :---- |
| リセットスイッチ<br>〓PTS？？？ | 4 ||

### 基板セットアップ

1. Base用スイッチプレート：捨て基板を切り離す。

    切り離す際にプレートが歪まないよう注意。

1. 基板Base：基板上下の製造タブをVカットに沿って切り離し、切断面を軽くやすりがけする。

1. 基板Base：`STLED`をジャンパして、USBコネクタを接続し、`STLED1`が緑に点灯することを確認する。

    点灯しない場合は、電源系、USBコネクタ等の問題を検査。

1. 基板Base：うら側の`SW1`と`SW2`へスイッチを取り付ける。

1. ファームウェアを書き込む

    1. `SW1`を押下しながらUSBケーブルを差し込む、またはUSBケーブルが差し込まれた状態で`SW1`を押下したまま`SW2`を押下して離し、`SW1`を離す。
        コンピュータ上で`RPI-RP2`というドライブが認識される。

    1. QMKコマンド、またはファイラー等を使ってファームウェアのファイルを`RPI-RP2`ドライブへ配置。

        ドライブの接続が解除され、USBデバイス（キーボード）として起動。

    1. Remapでスイッチソケットのパッドの反応を確認する

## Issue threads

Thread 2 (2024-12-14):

DN0010仕様検討

jpskenn, 2024-12-14:
## ざっくり要件

- 分割型
  →はい、分離型。
- 基本は分割型だが、パーツ追加で、一体型の左右が固定された状態でも使いたい。
  どちらの状態でも、テンティングが可能。
  何かしらの機構で左右を結合。左右の間隔は広げたり狭めたり、ある程度の幅で調整可能とする。
  左右を固定しない分割型だと、ちょっと動かしたりするときに配置が崩れてしまって、次に使うときにめんどい。
  左右をつないで固定しておけば、そういうときに便利。
  まずはテントさせて使うことを先にやってみたいので、一体型的なパーツが必要かどうかも含め、次期版とする。
  →次期版
- そもそも、両手にMCU必要なの？
  メリット
  - 左右どっちでもPCやMacに接続できる。（各個人のデスク環境に合わせた配置が可能）
  - どちらか一方だけでも使える。（片手用デバイス）
  - 通信ケーブルの信号線が少ない。4本。（5V、GND、TX/RX、LED？）
  デメリット
    - コスト増加
  コスト以外のデメリットはないので、金で解決できるなら乗せてしまってよい。
  実線配置は通信ケーブルがつらい。
  →両手にMCU乗せる。
- MCU直乗せをやめ、RP2040-Zeroなどを乗せる？
  Base基板をリバーシブルにしてコスト下げるなら、マイコンボードを乗せる方法となる。
  設計段階で、RP2040-Zeroのピン数（GPIO*20, 5v, 3v3, GND）に合わせて準備しておく。
  物理的に取り付け可能か、リバーシブルで対応できるかを調査。
  サイズ的には、SandyLPのBase基板（奥側に0.125u縁あり）で、R2に少しはみ出る程度。スイッチへの干渉なし。Choc V2初期型の固定ピンがギリだが、RP2040-Zeroの端子間にできるので問題ない。
  奥側を0.25uの縁にするなら、さらに余裕で収まる。
  問題は、Mid-ISOの中央ネジ穴にかぶること。ネジ穴をなくすとMid-ISOが3点支持となり、固定が厳しい。
  RP2040-Zeroをキーボード内側から2キー目の下（Mid中央、Rキーの下）なら干渉なし。ボトムへのネジ穴を移動させれば、そのまま乗せられる。
  RP2040-ZeroをリバースしてBase基板おもて側に乗せたとき、RP2040-Zeroうら側（上側）の部品はどれくらい飛び出ている？（RP2040とか乗ってる）
  1.6mm基板厚で、Mid基板まであと0.4mmしかない。レギュレータが1mmあるのでMid基板に当たる。Mid基板に切り欠き？
  Base基板のうら側へリバースせずに（リセットスイッチとかあるで）貼り付けだと、USBコネクタがBaseうら側に4.9mm（=基板 1.6mm＋USB 3.3mm）飛び出すため、こっちは完全NG。
  キーボード内側はTopの内側に0.625uの縁があるので、Base基板おもて側でTop基板の下あたりにRP2040-Zeroを配置し、Mid基板は切り欠きつけて干渉回避。なんとかなりそう。
  RP2040-Zeroから出てくる配線やネジ穴の配置で、Mid基板の切り欠きがイマイチな感じになる。
  →MCUは直乗せ。
- 必要ピン数（片手）：17本
  - マトリクス\*10（Row\*4, Col*6）
    SandyLPはRowを倍にしてピンを節約していたが、分割片手6列だと節約にならないので今回は行列そのままのピン数。
  - RE*2
  - LED*1
  - 通信（TX, RX）*2
    他にVSYSまたは3V3とGNDも通信線に含むが、GPIOとは別。
  - 親機判定ピン*1
  - スピーカー*1
  →上記のとおり。他に余ったピンは、ピンヘッダへ出しておく。
- 分割型のMCU配置とか、左右でGPIO違っててもええのん？それとも、同じピン使わないとだめ？
  左右で別々のGPIOを使用してOK。info.jsonのmatrixでそれぞれ指定。
  https://quefrency.net/post/2023-11-12/
  →左右で好きなピン使ってよし。
- QMKの左右どっちが親機？みたいなハードウェア的設定
  半田付けしないとだめ？DIPスイッチつける？
  ジャンパピンとかでもいい？
  USB_VBUS_PINでUSBが繋がってることをチェックするような設計とする。
  https://www.eisbahn.jp/yoichiro/2022/10/raspberry_pi_pico_split_usb_detect.html#gsc.tab=0
  Pi PICOは元々そういう風になっているが、空いてるピンをPICO同様に判定として使う。
  PICOのような仕組みがない場合は、次のように同様の仕組みを入れられる。
  https://yyoshisaur.hatenablog.com/entry/2023/03/05/120000
  さらに、VBUS（USBからの電源入力）とVSYS（親機との通信ケーブルからの電源入力）を分離するような設計とする。
  ふたつ目の例だと、USBは5V、通信は3V3で分けている。
  →GPIOを1本使って、親機（USBからの電源入力）の判定をおこなう。QMKで読み取り。
- 分割時の通信は、現在（2024-12-06）のところ、QMKの仕様でRP2040はシリアル通信のみ。
  参考：https://quefrency.net/post/2023-11-12/
  +,-,TX,RXでTRRS4線の全二重か、+,-,TX/RXでTRS3線の半二重。
  ピン余裕があるので全二重で。
  →はい、QMKでシリアル通信、全二重（回路的に左右でTXとRXはクロスさせる）。SIOでやる。
  →追加として、半二重での通信の検証ができるよう、回路を追加する。TRRSのRR（またはUSBのD+とD-）をジャンパで一つにまとめられるようにする。
- 分割した基板の接続方法は、USB Type-Cが望ましい。
  TRRSは使用中に抜き差ししたときに、電気的ショートが発生する
  また、TRRSコネクタは高さが5mmあるため、仕込む場所を選ぶ。
  TALPさんの販売ページにサイズが載っている。
  https://talpkeyboard.net/items/5fa25a06da019c17f0664dc7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
  USB Type-Cは、PCから左右間接続用コネクタに接続してしまった時に危険が危ないかもしれないが、基板間の接続は電源ピンを避けることで、そこまでやばくならないはず。
  また、左右間接続用コネクタから子機側のPC用コネクタに接続した時も、電源さえ通ってなければ、壊れることはないと思われる。
  ケーブル接続は、ボトムプレート裏面に、接続先（PCとKeyboard）のシルク入れる。
  しかし、TRRSは、PCと接続することはまずないため、安全と言える。
  TRRS H=5.0mm、USB Type-C H=3.2か3.3mm。
  TRRSでの接続とするが、構造的に薄さが必要な場合は、USB Type-Cとして再検討。
  →別項目「左右間接続コネクタの配置」で検討
- 左右間接続コネクタの配置
  - TRRSジャック
    Base基板おもて側：高さが5mmあるので、Mid基板とMid用プレートに切り欠きを入れないと入らない。
    Base基板うら側：SandyLPのボトムを超えてしまう。
    Mid中央基板うら側：Base基板に切り欠きを入れる。Base基板うら側へ、1.8mm（=5-2-1.2）飛び出す。
    Mid基板へ配置する場合、Top基板への分も含めると、8本（Row2、Col2、通信4）ネジ穴が必要となり、ネジ多すぎ問題が発生する。
  - USB Type-Cコネクタ
    Base基板うら側：SandyLPのPC接続用USBコネクタと同じ。
    キーボード奥側に配置すると、PC接続用と間違う可能性があるため、キーボード内側に配置。
  名の知れたCorne、Keyball、Lilyが、PC接続のUSB（ProMicro）が奥の内側で、TRRSは内側横出しなので、内側にコネクタがきてるのはおかしくない。
  キーボード内側、にTopより内側に0.625uの縁があるので、そこへBase基板にTRRSを配置して、Mid基板とプレートはなしで、Top基板で覆う。で配置できるか？
  配置はできそうだが、Mid基板とMidプレートに切り欠きを入れるのがイマイチ（TRRSの背が高すぎ）で、RP2040-Zeroの配置やネジ穴などを考えると、RP2040直乗せして、USB Type-Cで通信した方がすっきりする。
  →USB Type-Cで左右間通信。
- 左右間接続するコネクタの配置場所
  奥または横（内側）。
  奥は、左右間にコネクタ出てこないので多少すっきり。左右をくっつけ気味にもできる。
  横（内側）は、左右をくっつけ気味にできない。
  実際の使用で左右をどれくらいの間隔にして使うのかわからないが、横（内側）だとケーブルが当たるので、L字コネクタでも最低3u以上に広げないとだめかも。
  USBケーブルで接続する場合は、MCUのUSBコネクタから離れた位置にすると考えていたが、USBにする場合は横（内側）にして、刺し間違いを防ぐ。
  →TRRSの場合は奥（配置によっては横でも良い）。USBは横。
- 左右間接続のピン配置
  GND, VCC, TX, RXの4本を配置する。
  - TRRS
    参考：https://koktoh.hatenablog.com/entry/2024/05/10/191926
    →手前からGND, VSYS, TX, RXとする。
  - USB Type-C
    もしPCと接続してしまったときの安全性を考慮。
    USB2.0なType-cケーブル（SuperSpeedなピンがない）で使用できるようにする。
    信号的にはシールドされてるTX,RXピンを使いたいが、互換性のため使用しない。
    →GNDはGND、TXとRXはD+とD-、VSYSはVCC。
- LEDはどうする？
  WS2812BのV5か、WS2812Cにしとけば、LED信号を5Vに変換する必要ない。
  WS2812Bは背が高すぎ（H=1.57mm）なので、WS2812C（H=0.87mm）を、基板Baseおもて側へ表面実装する。
  https://akizukidenshi.com/catalog/g/g115068/
  →WS2812Cをデータ線の変圧なしで、そのまま使用。表面実装なので、ゴムシート等で光線漏れと光線混じりへの対策をおこなう。
- 左右間のLEDはどうなるの？通信？
  →左右それぞれでMCUに接続しておくだけでよい。レイヤーとかの状態はQMKで設定すれば通信される。
- 分割した基板の接続は、一体型で内部接続するときは、SHコネクタとか、他のものでもよい。
  →次期版
- もしかしたら無線（この場合、XIAO BLEとかをそのまま乗せる）
  どうせ据え置きでしか使わないので、設計とか電池とかに時間をとられたくない。
  無線で使用するシーンがない。
  →ボツ
- 基板Base、Mid、Topとボトムプレートは一体化（＝ねじ止めの意）していて、それより下にテント用のプレート、左右接続プレート？を用意する。
  →次期版
- パームレストを使わない範囲の設計にする
  使いたい人は使ったらいいけど、僕は使わないので、それ用に設計を考慮しない。
  →はい。基板外形は、ほぼSandyLPを半分にした感じ。
- 基板Mid中央、基板Topを分割し固定する方法
  Top基板がキー1個だけとかだと、基板のネジ固定が厳しいかも？
  また、キー1個だけのプレートだと、プレートが固定されてないので、スイッチが外れやすいのでは？
  スルーホールタップ（TH-0.8-1.0-M2とか）を使えば、プレートと基板をネジ止めできるので、なんとかなる？けど、金額的につらい。
  基板の奥を0.25uか0.5u、左右と手前を0.125uとするとしたら、Mid-ISOは、現在の左右外側でネジを逃す方法を、奥側へ変更できる。
  また、左右で内側になる方は、0.625uの縁があるので、そこもネジ止めできる。
  また、Mid中央とTopは左右に分割されるが、R3-R4のギャップ0.5uの隙間へネジを置けると思われる。
  プレートと基板を、間に1mmワッシャ（と1mmゴムシート）をかませて、ネジ止め？
  しかし、プレートより上にネジ頭を出したくない。（Choc V2スイッチ採用でキーキャップがプレートに当たりやすい。たまに当たってる。）
  →Top用スイッチプレートとTop基板は、キーキャップにかからないキーボード奥側と内側で2ヶ所以上ネジ止めして固定する。不要な導通がおきないように注意する。
- 製造する基板とプレート
  プレートTop、LR（1.2mm、リバーシブル、10x10）
  基板Top、LR（1.6mm、リバーシブル、10x10）
  プレートMid-ISO、LR（1.2mm、リバーシブル、10x10）
  基板Mid-ISO、LR（1.6mm、リバーシブル、10x10）
  プレートMid中央、LR（1.2mm、リバーシブル、10x10）
  基板Mid中央、LR（1.6mm、リバーシブル、10x10）
  プレートBase、LR（1.2mm、リバーシブル、右手側にロゴ、2枚に分ければ10x10）
  基板Base、LR（1.2mm、左右の基板を1枚に面付け、SMTA）
  ボトムプレート（1.6mm、Base基板の部品配置を左右対称に頑張ればリバーシブル）2枚
  →〓後から・基板設計にともない決めていく。
- 基板とプレートの積層構造
  プレートTop 1.6mm
  ゴムシート 1mm
  基板Top 1.6mm－－－－－基板Top 1.6mm
  　　　　　　　　　　　　　ゴムシート1mm（本来0.9mmの空間に詰める）
  　　　　　　　　　　　　　プレートMid 1.6mm
  スペーサー3.5mm　　　　　　ゴムシート 1mm
  基板Mid 1.6mm－－－－－－－基板Mid 1.6mm
  　　　　　　　　　　プレートBase 1.6mm
  スペーサー 2mm　　　ゴムシート 1mm
  基板Base 1.2mm－－－基板Base 1.2mm
  ボトムプレート1枚目 1.6mm
  ボトムプレート2枚目 1.6mm
  →〓後から・基板設計にともない決めていく。
- 各基板とプレートでネジ穴位置合わせる？
  →〓後から・基板設計にともない決めていく。
- ボトムプレートとBase基板のネジは、Base基板より上のネジと別にしておく
  Base基板より上はピンの信号が通るので、それがボトムまでくるとボトムが金属に触れたとき入力がおかしくなる可能性。
  →はい。ボトムプレートのネジ類はBase基板のみに接続とする。
- 基板間接続でナットの使用数を減らしたい。
  スペーサーとして使用する、ナット+ワッシャーの2mmのやつは別として、基板等の組み合わせ後にナットで締め付けるのは作業が面倒なので、減らしたい。
  →はい、できたら減らす。
- Base基板とボトムプレートで薄くする
  現在は、Base基板下 4.6mm（= スペーサー（3mm） + ボトムプレート（1.6mm））
  - 2.5mmのスペーサーに変更（-0.5mm）
    MAC8スルーホールタップ使用。
    金額がつらい。
    たぶんボツ。
  - ボトムプレートにソケット等の逃し穴を開けて、Base基板に密着。
    パーツを逃す穴を開けたボトムプレートをBase基板に密着させる。
    パーツの飛び出しは、ソケット1.8mm、スイッチの中央足2.1mm（Base基板が1.2mmの場合）、MCUとかは低め。
    これとは別にUSBコネクタが3mm程度で、これは以前からボトムプレートに切り欠きをつけている。
    ボトムプレートを1.6mm*2枚にすると3.2mm。これならパーツは飛び出さず、SandyLPから-1.4mm。USBコネクタが机スレスレの予定だが、テントさせるのでスレスレは若干緩和されそう。
    ボトムプレートを1.2mm*2枚にすると2.4mm。こちらもパーツは飛び出さないが、薄いゴム足だと、USBコネクタが完全に机に当たってしまうので厳しいと思われる。
    単純に穴をあけたボトムプレートを2枚重ねにすると、MCUとかが外から見えててちょっと嫌なので、ボトムプレートA（MCU等の穴あり）、B（ソケットとスイッチ中央足の穴だけ）の2枚にする？コスト増に注意。
    AとB両方とも1.6mmのつもりだが、USBコネクタがなんとかなりそうならBを1.2mmにしてさらに薄くしてもよい。
    MCUをキーボード内側のMidとTopの下へ配置するので、USBコネクタも内側への配置となる。
  →〓後から・基板設計にともない決めていく。
- FR-4なものは、できれば100mm*100mm以内のサイズで製造してコストを下げる。
  細かく分割とかいろいろ考えることが多くなるようならパスしてOK。
  →はい。なるべく100mm*100mm以内のリバーシブルで作っていく。
- レイアウト、特にマクロ的に使用する中央部はどうする？
  R2（Q行）の中央は、指が届かないので、何も考えずになくしてよい。
  R3（A行）の中央は、指が届き、マクロで使えるのであるとよいが、レイヤーでなんとかなるのでなくてもよい。
  R4（Z行）の中央は、指が届き、DM_PLYとしてレイヤーに入れずに使いたいので、必ず入れる。
  →R2とR3は中央削除し、R4は中央を残して、それぞれ6列。R5はSandyLPの4列の外側にREを足して5列。
- ロータリーエンコーダはどこへ？
  R5の5列の一番外側をRE搭載可とする。（左右とも）
  →レイアウトの結論を参照。R5の外側へ置く。
- Sandyの3段階の高さは変更なし。
  Sandyの3段階の高さは、各指に対する補正をかけているだけなので、テントしてもそのまま。
  テントしたいのはスイッチプレート全体の平面であり、こちらは、手首に対する補正。
  なんだけど、テントしたときに補正具合が変わるかもしれないので、実機で試して、次期版での対応とする。
  →変更なし。使用感を試す。（変更する場合は次期版。）
- 必要であれば、スイッチプレートとかを貫通するスペーサーの穴を、6角形にする。
  組み立てしやすくなる？
  →はい。できるところはやる。
- テンティング機構
  - 全般、概念的なこと
    - 何らかの角度調整機構。
      →はい。
    - テンティング機構を入れても、SandyLPより悪くならないこと。
      例：キーボードの最低高が高くなってしまったりしないこと。
      →はい。左右の縁を0.25u→0.125uに変更してテントしたときの小指キーの持ち上がりを減らす。
    - SandyLPはキーボード外側に0.25uの縁があるが、外側の底辺を支点にテントすると、一番外側のキーがSandyLPよりも位置が高くなるので要改善。
      縁をなくすと、キーボードの端でキーキャップ下端が指に引っかかるので、縁はつけたい。
      縁について、奥を0.25uか0.5u、左右と手前を0.125uとしたらどうか？
      →はい。奥を0.25uか0.5u、左右と手前を0.125uとする。奥は基板開発時に考える。
    - テント機構はキーボードの機構とは別にしてよい。
      →次期版。
    - 手をのせた時の強度
      SandyLPをそれっぽい感じで持ち上げてみたが、ぐにゃっとしたりはしない。
      →SandyLPと同様の構造でいける。
  - テント角
    一体型のSandyLPを普通に使っている感じで腕を自然に前に出すと、手首の親指側が浮いている（SandyLPで打鍵するときには、キーに指を乗せるため、親指側を少し下げている）。
    その手首の角度に合わせるようにテント角を持っていきたい。
    「垂直に立てる」みたいなことはやる気なし。
    リストレストが必要になってくるほど、角度をつけることもやる気なし。キーボードの手前に物を置いたり、作業したりするので、机を広く使えるよう、リストレストは使わない。
    最初は3度（消しゴム1個をキーボードの下に挟む程度）くらいから始めるのかな？
    目標は、0度（SandyLP同等）〜15度くらい。
    →はい。とりあえず、実機で試す。
  - 手前と奥でテント角変える？チルトと混ぜたような感じ？
    4隅をネジ足にするような方法で実現。
    何かよいのがあればやる程度。
    まず、単純なチルトなしのテントでいろいろ試して、どうするか考える。
    →まずは試す。ゴム足で対応できるところはゴム足でなんとかする。4隅で調整などは次期版。
  - 構造
    - 単純に、背の高いゴム足を貼り付けるだけ。
      →はい。まずはここらへんから。
    - 単純に、角度調整足を買ってきて貼り付けるだけ。
      https://superhahnah.com/try-tenting-split-keyboard/
      https://www.evbart.com/a-simple-tenting-solution-for-ergonomic-keyboards/
      スマホスタンドもあるが、低い角度には対応しない。
      https://www.sanwa.co.jp/product/syohin?code=PDA-STN33BK
      Manfrottoのポケット三脚 MP3-BK
      https://www.manfrotto.com/jp-ja/pocket-support-large-black-mp3-bk/
      ノートPCとかに貼り付けるスタンド。チルト足。
      https://www.amazon.co.jp/ノートパソコン-（2個入）貼り付け型-ノートPCスタンド-持ち運びに便利-（シルバー）/dp/B0CZDK3RJ5?source=ps-sl-shoppingads-lpcontext&ref_=fplfs&ref_=fplfs&psc=1&smid=AQLSP0LL8JZWT
      https://www.yodobashi.com/product/100000001005882452/
      https://www.yodobashi.com/product/100000001005945121/
      左右を結合する方法は？
      →はい。まずはチルト足とかで試す。左右結合は次期版。
    - 左右結合機能をもたせたボトムプレートとテンティングプレート
      コの字型（右側はコ、左側はコの逆→匚。）のボトムプレートの真ん中に、－横棒型のジョイントプレートを入れて、左右間を接続。匚－コ
      コの字型のボトムプレートは、同じくコの字型のテントプレートに、蝶番で接続され、天とする。
      テントプレート何かしらの角度固定機構を持つ。
      このままでは、ボトムとテントが段になり、キーボードの高さが1枚分高くなってしまう。
      トルクヒンジ？
      蝶番を真ん中に持ってくるスタイル
      https://note.com/mogma_products/n/n710ba24c9c51?sub_rt=share_h
      →次期版

## 番外
- I2Cのピンを出しておく。
  抵抗とかは未実装でよい。
  →はい
- 親指にHATスイッチ？
  置くところがない。
  →ボツ
- DIPスイッチつける
  用途未定。（WindowsとMacでキーマップ分けるとか？）
  https://akizukidenshi.com/catalog/g/g108929/
  →Base基板うら側へ4Pつける。ボトムプレート側からアクセス可能とする。
- SWDコネクタ類をボトムプレート側からアクセス可能とする
  →はい。どうしてもボトムプレートの切り欠きが大きくなりすぎる場合は別の場所でも良い。

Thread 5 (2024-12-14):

名前

jpskenn, 2024-12-14:
## 決定
一体型のSandyLPを元にした、分割型のバリエーションモデル。
SandyLPのコンセプトはそのままに、分割型として左右ふたつのペアを想起させる「Duo」をつけた。
**「SandyLP Duo」**

## 案（選考過程）

案出し
- SandyLPs：分割して複数になったイメージ。
- SandySPL：分割のSPLit（スプリット）と、SPeciaL（スペシャル＝特別）な意味を混ぜ込み。
- SandyDLP、LPD：分割のDivide、ふたつやペアのDuo、Duet、Double、Dual、ふたつの要素や部分からなるもの、ふたつの重要な関係としてのDyadなどの「D」。

「分割」であることをわかりやすく強調したいので、「D」とかの一文字ではなく、Dで始まる単語をそのまま使う。
Dyadは意味としては一番好きだが）、単語がマイナーすぎて伝わらないのでボツ。
Divideは分割しただけで、「ふたつ」と「ペア」の意味が薄すぎなのでボツ。
Duetはカラオケとかで歌う音楽的な感じが強すぎるのでボツ。
DoubleとDualは「ペア」の意味が薄いのと、「ふたつ」が2倍になるような雰囲気が強めなのでボツ。
で、Duoを採用し、「SandyLP Duo」に決定。

中学生か高校生くらいのときに憧れていた、PowerBok Duoとか格好良すぎるでしょ。

Closed 2024-12-14.

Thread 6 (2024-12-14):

ボトムプレートの構造

jpskenn, 2024-12-14:
Base基板うら側から、ボトムプレートまでの構造
SandyLPの4.6ｍｍ（スペーサー3mm＋プレート1.6mm）よりも薄く、強くしたい。

Base基板裏側の突起物（Base基板 t=1.2mmとした場合）
- 隠すもの
  - Choc V2スイッチ中央足：2.1ｍｍ
  - Choc用ソケット：1.85mm
  - スイッチ用ダイオード：1.35ｍｍ
  - Mid基板、Top基板へのネジ頭：0.6mm（Wilco F-0000N-02）
- 切り欠きつけるもの
  - リセットスイッチ（PICOとかについてるタイプ）：2.5ｍｍ
  - USBコネクタ：3.2ｍｍ
  - DIPスイッチ：2.3ｍｍ

案
Base基板より下を、以下の構造とする。3.4mm。
ゴムシート t=1.0mm：パーツを避けて貼り付け
FR-4 t=1.2mm：背の高いパーツ部分に穴あけ。
FR-4 t=1.2mm：USBコネクタ以外は、全てカバーした状態。

ねじ止めはどうする？

- その他（メモ）
  - RP2040-ZeroをBase基板うら側からリバースマウント（USBコネクタが上）になるように取り付けた場合。
    Base基板おもて側へのUSBコネクタの飛び出し2mm弱 = USBコネクタ3.16mm - Base基板厚1.2mm
    Base基板うら側への飛び出し = Zero基板厚1.6mm + レギュレーター等パーツ2mm弱（実測必要）

jpskenn, 2024-12-22:
Baseにスルーホールタップを付けておき、ボトム底面からネジ止め。

jpskenn, 2024-12-25:
基板Baseには、基板Midへのスルーホールタップも取り付けるが、これをボトムプレートのネジ止めにも使用する。

Closed 2024-12-25.

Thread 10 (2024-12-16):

BaseとMid、MidとTopのネジ穴を共通に？

jpskenn, 2024-12-16:
Midのネジ穴を減らしたいので、ネジ穴を共通に。

Baseおもて側にスルーホールタップ2mm。
Midおもて側から3mmネジどめ。
MidとTopの間にネジ穴なしのスペーサー3.5mmを入れて、Topおもて側から8mmネジ止め。

Topプレートの固定は？

jpskenn, 2024-12-22:
スルーホールタップで固定。
続きは以下
https://github.com/jpskenn/SandyLP-Duo/issues/11

Closed 2024-12-22.

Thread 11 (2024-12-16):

Top用スイッチプレートの固定方法

jpskenn, 2024-12-16:
1キーだけなので、ソケット緩くなってきたら、プレートごとスイッチ外れそう。

jpskenn, 2024-12-17:
基板Topとネジ止めする。
間に、樹脂ワッシャー（ヒロスギとか）のt=1.0mmを挟んで、ネジとワッシャーでとめる？
→組み立てできない。

1mmのスルーホールタップならOK。
TH-1.6-1.0-M2 など
TH-0.8やTHCなどでもよい。設置が厳しいなら小径タイプでもよい。

jpskenn, 2024-12-17:
普通の（スペーサーなしの）スルーホールタップをTop基板うら側へ取り付け、
間に樹脂ワッシャーt=1.0mmを挟み、
スイッチプレートからネジ止めでもよい。

こちらなら、スルーホールタップを使いまわしできるかも？

jpskenn, 2024-12-22:
MidとTopのプレートはスルーホールタップでネジ止め。

jpskenn, 2024-12-23:
1mmのスルーホールタップを、基板Top、Mid-ISO、Mid-CNTのおもて側に取り付け、それぞれのスイッチプレートおもて側からネジ止めする。
このネジは外から見えるので、装飾的な感じで配置し、使用するネジも色や形状を変えたりしたい。

jpskenn, 2025-01-04:
1mmのスルーホールタップで対応した。

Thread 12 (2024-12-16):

ChocとMX両対応

jpskenn, 2024-12-16:
RE以外は、割と配置できてしまいそう。
MidのプレートとTopの基板がツライチになるんだっけ？

jpskenn, 2024-12-22:
MX対応する場合の追加作業。
- ボトムプレートのソケット避けの穴あけ。
- 基板とスイッチプレート間隔変更。
- MidにTop重ねられる？

jpskenn, 2024-12-25:
さっさとDN0010を開発して、テントを試したい気持ちが強いので、両対応は見送りの予定。

jpskenn, 2024-12-30:
しかし、MXのスイッチも使いたい気持ちはけっこうある。

jpskenn, 2024-12-31:
>>https://github.com/jpskenn/SandyLP-Duo/issues/12#issuecomment-2558353001
MXの場合は、Mid用スイッチプレートとTopが1枚の基板になるので、基板製作自体が変更となる。

jpskenn, 2025-01-06:
Mxの足は
Base→ボトム
Mid→Baseに当たらないか？

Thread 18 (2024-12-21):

ボトムプレートのサイズ

jpskenn, 2024-12-21:
ボトムプレートの左右、特に外側になる方の辺を数mm短くして、テントさせるときの支点をちょっとだけオフセットすることで、小指側の持ち上がりをなるべく少なくする。

jpskenn, 2024-12-21:
左手用の場合、
左下のネジを左上のネジ（Mid-ISOと共用）の位置まで、基板端から移動させる。

jpskenn, 2024-12-21:
ボトムAとBで基板幅を変更中

jpskenn, 2024-12-21:
ボトムプレートAの穴と基板端が近いが、一旦Close。

Closed 2024-12-21.

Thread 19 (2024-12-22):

スルーホールタップの接続先のマウンティングホールをφ=4.6mmのパッドに変更。

jpskenn, 2024-12-22:
スルーホールタップがφ=4.5mmなので、誤差を含めて余裕を持たせて受けるように。
金属コンタクトが必要なので、もう少し余裕をもたせて4.7-4.8ｍｍとかでもよい。

必要なら穴位置調整。（Mid中央の内側がきびしい）

jpskenn, 2024-12-22:
BaseからのMid-ISOとMid-CNT。
ネジ位置、スイッチソケットのパッド干渉調整など。

Closed 2024-12-22.

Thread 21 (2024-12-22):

部品発注

jpskenn, 2024-12-22:
自宅在庫を確認して、最低1台、可能なら5台分の部品を発注。

1台分
- [x] スイッチ 45個（家にGhostがあるが、少し軽めのものを追加）
- [ ] スルーホールタップ 2mm 22個
- [ ] スルーホールタップ 1mm 18個
- [ ] ネジ 8mm 12個
- [ ] ネジ 3mm 16個
- [ ] ネジ 3mm（プラ） 12個
- [ ] ネジ 5mm（プラ） 16個
- [ ] ゴムシート t=1mm
- [ ] ゴムシートt=2mm（最悪、1mmの2枚重ねでも）
- [ ] ポロンシート t=1.5mm
- [ ] テント用スタンド
- [ ] 小さ目の半球型ゴム足（外側支点用）
- [ ] 短めのType-c to Type-cコネクタ

他には？

jpskenn, 2024-12-27:
半球型のクッションゴムを探している。
https://www.yodobashi.com/product/100000001003359892/

jpskenn, 2025-01-04:
USB-C コネクタキャップ
WS2812C-2020

発注済み

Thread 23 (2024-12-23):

調査　RP2040のシリアル通信

jpskenn, 2024-12-23:
全二重でのシリアル通信。
TXとRXをクロスさせるのは対応済み。

ピンの指定はOK？
プルアップ抵抗が必要か？
ソフトウェアの実装方法は？

jpskenn, 2024-12-23:
https://quefrency.net/post/2023-11-12/

ピンはGPIOの0と1で全二重。左右でクロスさせる。
全二重はプルアップ抵抗不要。

半二重はプルアップ抵抗が必要だが、ドライバでPIOを使えば不要だが、PIOは他でも使われるかもしれない。

→全二重だけのサポートとする

Closed 2024-12-23.

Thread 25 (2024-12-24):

ボトムプレートAのスイッチ毎の切り欠きをフットプリント化

jpskenn, 2024-12-24:
固定ピンも穴開ける。

jpskenn, 2024-12-25:
右手左手で、ボトムプレートAをリバーシブルにすると、ソケットの向きが逆になる。
- ボトムプレートAを、左右別に製造する？
- ソケット両方向に対応するカットアウトを入れたフットプリントにする？

jpskenn, 2024-12-25:
ボトムプレートAは、10x10で作って、かなり大きな穴を3つくらい開けたフレームだけにする？

jpskenn, 2025-01-01:
スイッチごとに穴を開けるのではなく、行ごとに大穴を開ける方向に変更。

Closed 2025-01-01.

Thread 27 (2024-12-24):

ビルドガイド　REのピンがボトムBに当たる

jpskenn, 2024-12-24:
リセットスイッチ
REの固定足。ピンも？

jpskenn, 2024-12-24:
EC11 ピン　3.5mm
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

EC12 ピン　3.5mm
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

jpskenn, 2024-12-24:
ピン　3.5mmは、ボトムプレートBへの干渉あり。

ボトムプレートBまでのクリアランス＝3.4ｍｍ
基板Base 1.2ｍｍ
ゴムシート 1.0ｍｍ
ボトムプレートA 1.2ｍｍ

jpskenn, 2024-12-24:
ボトムプレートBに穴あけするのは見た目的にイマイチなので、開けたくない。

現物合わせであたりそうなら、ピンを斜めに倒すか、先端をほんの少しカットすれば回避可能。
ピンを倒しやすいように、ボトムプレートAのピン逃し穴を大きめにする。
→ビルドガイドに記載。

jpskenn, 2024-12-24:
ボトムプレートBは、このあたりで対応。
571253b962d57ac051ef91e3c8eb1155edcc9814

残作業：ビルドガイドへの記載

Closed 2025-01-06.

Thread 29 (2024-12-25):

ボトムプレートA 真ん中のネジ位置を調整

jpskenn, 2024-12-25:
真ん中のネジ穴（H_btn1）が、ソケットのカットアウトにかかる。
ネジ位置をカットアウトにかからない場所へ移動させる。

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

jpskenn, 2024-12-25:
0.5u内側のちょい手前、キーとキーの間くらい？

jpskenn, 2025-01-01:
8a4ff0cfcde359d60fe9dabf003c38cf9c8ccdad

jpskenn, 2025-01-01:
bd3a403cc82916cf71d946cfb8ea3b1829d21d76

Closed 2025-01-01.

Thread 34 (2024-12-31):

Readme 動機的な話

jpskenn, 2024-12-31:
ErgoDashを買って自キの世界に飛び込んだのは、
- 分割型
  手を体の前に寄せない。
  肩を自然に開いた打鍵ポジション。
- 左右対称
  レガシーロースタガに対する違和感。
- 指の長さに合わせた配列
  このときはカラムスタガが解決してくれると思っていたけど、ErgoDashは自分には合っていなかった。
  今なら、Sandy（＝Jonesの配列＋スイッチの3D配置）によって自分の指に合う配列がある

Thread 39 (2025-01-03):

ボトムB ケース接続用ネジ穴タブにスルーホールタップつけて、テント・チルトをローレットネジで？

jpskenn, 2025-01-03:

jpskenn, 2025-01-03:
M3以上

jpskenn, 2025-01-04:
Glove80はM4のネジ

jpskenn, 2025-01-04:
参考：[Corne V2のチルト・テントプレート](https://github.com/foostan/crkbd/blob/main/docs/corne-cherry/v2/buildguide_tilting_tenting_plate_jp.md)

jpskenn, 2025-01-04:
まずは、大きめのゴム足や、ノートPC用チルトスタンドなどで試し、細かな調整や、チルト・テントを合わせたものが必要となった場合に、ボトムプレートを改造・発注するのでもよいのでは？
また、ケースの取り付けなどとの兼ね合いも考える必要がある。

jpskenn, 2025-01-05:
#41 のMagSafeでテントも、こちらで扱う。

jpskenn, 2025-01-05:
棒の角度
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

構造　テント機構 #33　をここへ合流。

jpskenn, 2025-01-05:
ケース 底の厚みで角度変える #37　をここへ合流。

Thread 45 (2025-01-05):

基板Base 左右間のUSBに保護回路？

jpskenn, 2025-01-05:

jpskenn, 2025-01-05:
- フェライトビーズ　Extended
- ポリヒューズ　つけてる
- TVSダイオード（過電圧・静電気保護、電源用）
- 逆電圧保護
    ショットキーダイオードで、左右間の方向決めてるので、今回は除外。
- 電力分配（過電流保護、ヒューズと効果重複）
  どうする？
- ESD保護ダイオード（過電圧・静電気保護、D+/D-用）　つけてる
- 逆流防止（左右をつないで両方、または片手に2本ともホストUSBを差したときの逆流） Extended
  ゴムキャップでなんとかならんか？（片手に2本ともホストはダメかも）

jpskenn, 2025-01-05:
Pi PICOのDatasheetに、ショットキーダイオードかP-FETで保護する記載あり。
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

jpskenn, 2025-01-05:
Pi PICOは電源まわりの保護がシンプル。
これを基本に、逆流防止だけ入れていく感じにしたい。

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

jpskenn, 2025-01-05:
左右間通信用コネクタにも、ESD保護入れる。

jpskenn, 2025-01-06:
PICOはショットキーダイオード。
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

jpskenn, 2025-01-07:
現在
VBUS→SD→5V→TRANS→3V3
としているところを、
VBUS→SD→VSYS→TRANS→5V＆3V3
にならんか？

jpskenn, 2025-01-07:
ショットキーダイオードを、MOSFETとトランジスタへ置き換える。

https://jlcpcb.com/partdetail/Alpha_OmegaSemicon-AO3401A/C15127
https://jlcpcb.com/partdetail/DiodesIncorporated-DMMT5401_7F/C154733

jpskenn, 2025-01-09:
置き換え完了
7a40f2b54248456473dc4c00c7824b1b0d4b2c3f

jpskenn, 2025-01-09:
左右間接続
- [ ] ESDつける
- [ ] ポリヒューズつける

jpskenn, 2025-01-10:
aaa7f187366cb4aabb8691401fcbc0ef9e3261d1

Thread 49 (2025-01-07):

基板Base　左右間接続の5Vはどこへつなぐ？

jpskenn, 2025-01-07:
一般的な分割型キーボードで、片方から出た5Vはどこにつながっている？

jpskenn, 2025-01-07:
lunakey PICO
片方のVSYSを、相手のVSYSへ。
Pi PICOでの動作だが、このVSYSはUSBのVBUSがショットキーダイオードを通ってきただけのもの。

RP2040で作る自作キーボードの本の作例
片方の5Vを、相手の5Vへ。
この5Vは、USBのVBUSがショットキーダイオードを通ってきただけのもの。

Closed 2025-01-07.

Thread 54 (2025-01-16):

DIPスイッチ小さすぎ

jpskenn, 2025-01-16:
HHKB程度のスイッチでないと、操作できない。

jpskenn, 2025-01-21:
スルーホールタイプは、どれも基板から5mm程度の高さになる。
https://akizukidenshi.com/catalog/g/g100586/
https://akizukidenshi.com/catalog/g/g108923/
ピアノタイプは高さ10㎜弱。
https://akizukidenshi.com/catalog/g/g115243/

フットプリントは、2.54mmピッチの幅7.62mmで共通。

jpskenn, 2025-01-21:
表面実装：1.27mmピッチ、幅7.6mm
スルーホール実装：2.54mmピッチ、幅7.62mm

このふたつのうち、どちらかを実装できるように、フットプリントを少しずらして配置。

jpskenn, 2025-01-21:
DIPスイッチ、リセットスイッチ、電源LEDを、基板の端へ寄せてもいいかもしれない。

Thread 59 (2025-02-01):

レイアウト変更案、LED位置の変更

jpskenn, 2025-02-01:
スペースキーを1uにして、最下行で一番中央寄りのキー（以下、中央キーと言う）を、外側へ0.25uずらす。

片手キーボードを体験した結果、中央キーが少し遠く感じる。

ついでに、LEDを中央キーの隣に配置できないか？

jpskenn, 2025-02-01:
[KLE[(https://www.keyboard-layout-editor.com/#/gists/d6cedbae3057c743fbb2920af3980040)

jpskenn, 2025-02-01:
最下行、全体的に0.125u外側へ移動してもいいかも。

jpskenn, 2025-02-01:
QWERTY行を外側へすこしずらしてもいいかも。
0.125〜0.5uの範囲で確認。
Treadstone的な感じに近づく。

jpskenn, 2025-02-02:
中央キー、できれば0.25uくらい内側にしたいが、他のキーはこれが最適。
可能なら、Midにする？

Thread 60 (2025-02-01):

片手で使えるキーマッピング

jpskenn, 2025-02-01:
FLIPキーを押してもう片方のキーを入力でき、モディファイアを含めて、片手でも使えるキーマッピングを用意する。

jpskenn, 2025-02-02:
MatiasのHalfキーボードに比べてキーがちょっと少ないので、何らかの方法で対応する。

jpskenn, 2025-03-04:
Tap-Danceで、Base、数字、記号の各レイヤーを遷移できるようにはした。

しかし、この方式では、フロッギーのようなダイレクトな入力ができず、遅い。

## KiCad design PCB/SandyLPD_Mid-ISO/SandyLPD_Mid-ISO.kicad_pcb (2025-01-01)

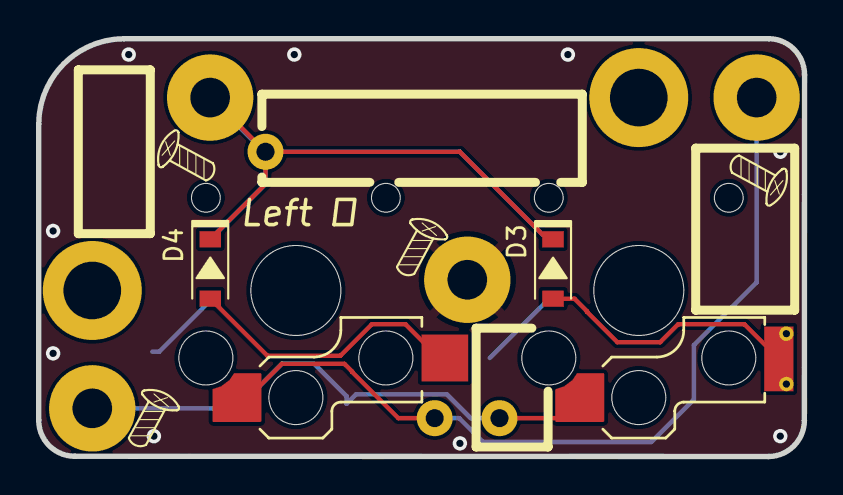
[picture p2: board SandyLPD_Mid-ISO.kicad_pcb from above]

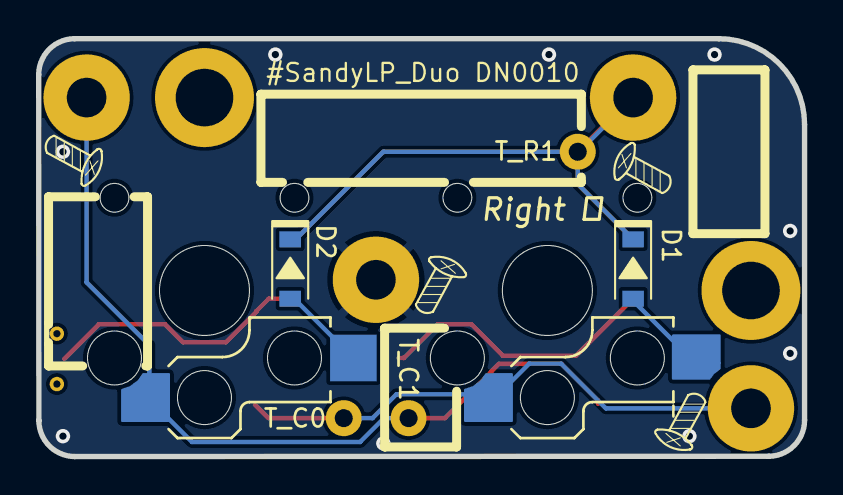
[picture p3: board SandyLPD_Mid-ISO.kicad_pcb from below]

Board: 2 copper layers, 42.5 x 23.2 mm, 18 parts (11 on the bottom side), 7 nets.

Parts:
Cutout1: 60_Outline; SandyLPD_outline_Mid-ISO
D1, D2, D3, D4: D; D_SOD-123_Emphasized_Direction_Line
H1, H2, H3, H4: MountingHole; MountingHole_2.2-4.8mm_M2_Pad_minimal_for_Through-hole_tap
H5, H6: MountingHole; MountingHole_M2_Through-hole_tap_THC-0.8-x-2
SW_BS1: SW_Push; Kailh_socket_ChocV2_for_Reverse_no_hole
SW_P1: SW_Push; Kailh_socket_ChocV2_small_#2pad_for_Reverse_no_hole
SW_Q1: SW_Push; Kailh_socket_ChocV2_for_Reverse
SW_TAB1: SW_Push; Kailh_socket_ChocV2_for_Reverse_narrow_#1_and_#2pad
T_C0, T_C1: Conn_01x01; TestPoint_THTPad_D2.0mm_Drill1.0mm
T_R1: Conn_01x01; TestPoint_THTPad_D2.0mm_Drill1.0mm

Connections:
LR_Mid-ISO_col0: H2.1, SW_P1.1, SW_TAB1.1, T_C0.1
LR_Mid-ISO_col1: H3.1, SW_BS1.1, SW_Q1.1, T_C1.1
LR_Mid-ISO_row0: D1.1 (K), D2.1 (K), D3.1 (K), D4.1 (K), H1.1, T_R1.1
unnamed: D1.2 (A), SW_TAB1.2
unnamed: D2.2 (A), SW_Q1.2
unnamed: D3.2 (A), SW_P1.2
unnamed: D4.2 (A), SW_BS1.2

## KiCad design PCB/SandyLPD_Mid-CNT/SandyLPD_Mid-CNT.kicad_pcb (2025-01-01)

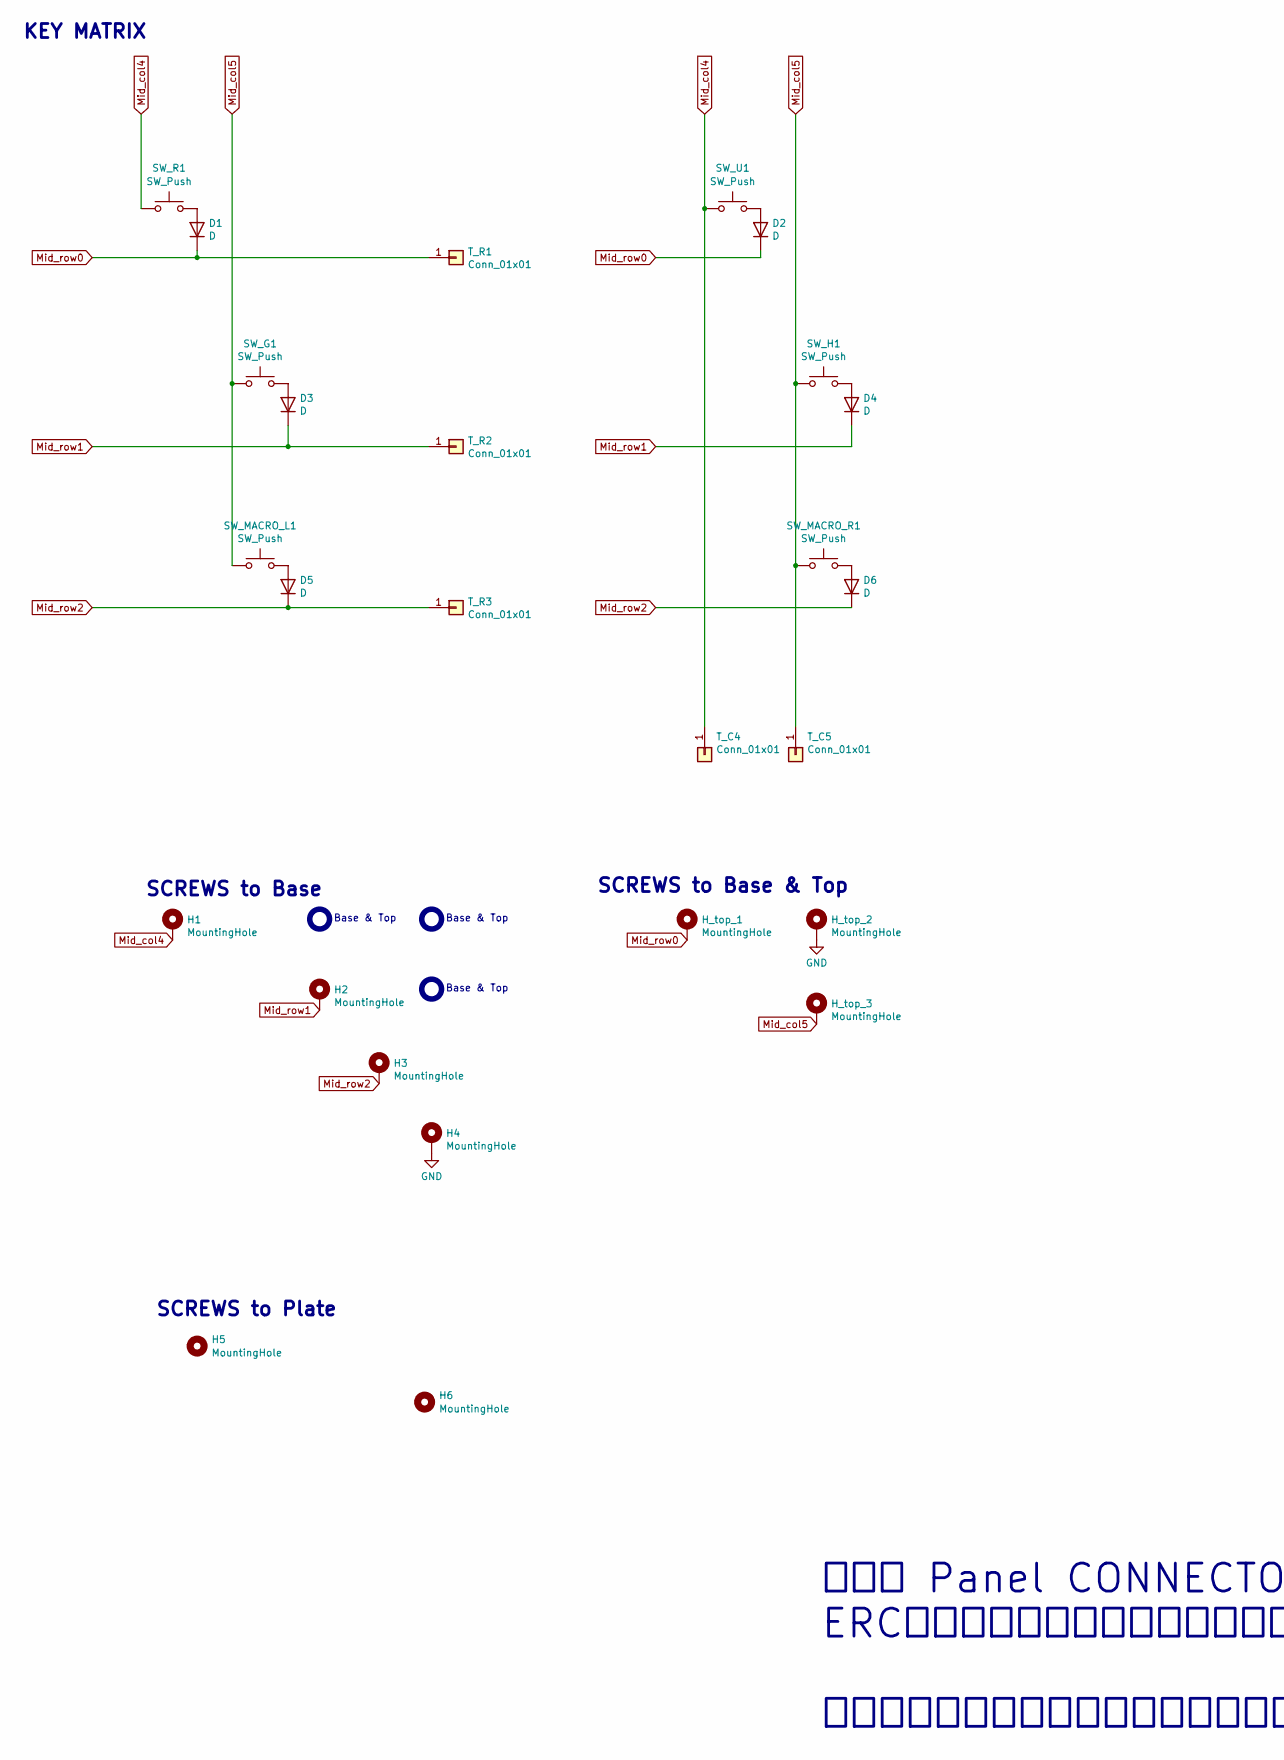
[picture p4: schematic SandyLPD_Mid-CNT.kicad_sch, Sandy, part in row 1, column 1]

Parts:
D1, D2, D3, D4, D5, D6: D; D_SOD-123_Emphasized_Direction_Line; LCSC C81598
H1, H2, H3, H4: MountingHole; MountingHole_2.2-4.8mm_M2_Pad_minimal_for_Through-hole_tap
H5, H6: MountingHole; MountingHole_M2_Through-hole_tap_THC-0.8-x-2
H_top_1, H_top_2, H_top_3: MountingHole; MountingHole_2.2-4.8mm_M2_Pad_minimal_for_Through-hole_tap
SW_G1: SW_Push; Kailh_socket_ChocV2_small_#2pad_for_Reverse_no_hole
SW_H1: SW_Push; Kailh_socket_ChocV2_for_Reverse
SW_MACRO_L1: SW_Push; Kailh_socket_ChocV2_small_#2pad_for_Reverse_no_hole
SW_MACRO_R1: SW_Push; Kailh_socket_ChocV2_for_Reverse
SW_R1: SW_Push; Kailh_socket_ChocV2_small_#2pad_for_Reverse_no_hole
SW_U1: SW_Push; Kailh_socket_ChocV2_for_Reverse
T_C4, T_C5: Conn_01x01; TestPoint_THTPad_D2.0mm_Drill1.0mm
T_R1, T_R2, T_R3: Conn_01x01; TestPoint_THTPad_D2.0mm_Drill1.0mm

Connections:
GND: H4.1, H_top_2.1
Mid_col4: H1.1, SW_R1.1, SW_U1.1, T_C4.1
Mid_col5: H_top_3.1, SW_G1.1, SW_H1.1, SW_MACRO_L1.1, SW_MACRO_R1.1, T_C5.1
Mid_row0: D1.1 (K), D2.1 (K), H_top_1.1, T_R1.1
Mid_row1: D3.1 (K), D4.1 (K), H2.1, T_R2.1
Mid_row2: D5.1 (K), D6.1 (K), H3.1, T_R3.1
unnamed: D1.2 (A), SW_R1.2
unnamed: D2.2 (A), SW_U1.2
unnamed: D3.2 (A), SW_G1.2
unnamed: D4.2 (A), SW_H1.2
unnamed: D5.2 (A), SW_MACRO_L1.2
unnamed: D6.2 (A), SW_MACRO_R1.2

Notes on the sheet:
Base & Top
以下の Panel CONNECTOR は、Baseからコピペ。 ERCの警告「別パネルのラベルがどこにも接続されていない」は、無視してOK。 ！！！他の警告（ラベルかぶりとか）は、しっかりチェックせよ！！！
SCREWS to Plate
SCREWS to Base
SCREWS to Base & Top
KEY MATRIX

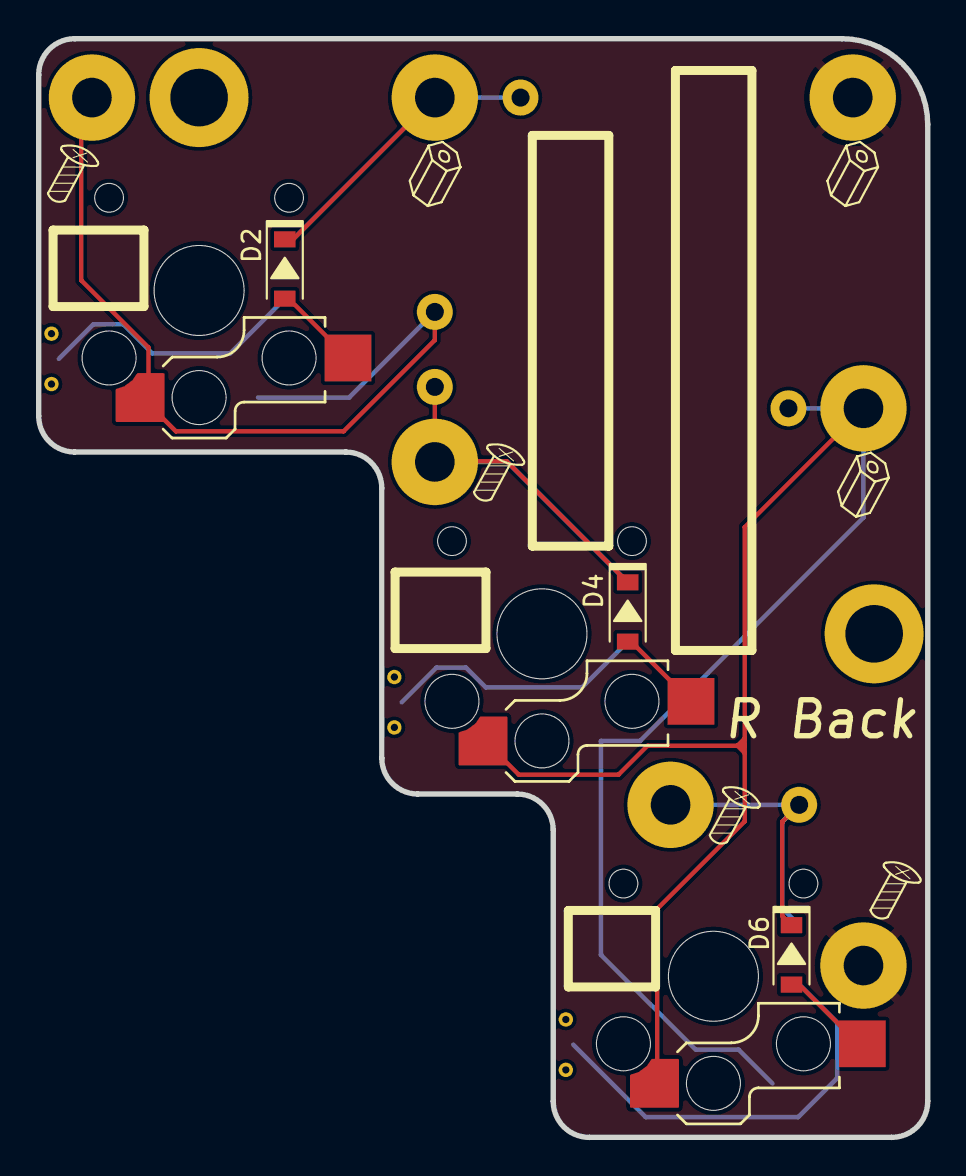
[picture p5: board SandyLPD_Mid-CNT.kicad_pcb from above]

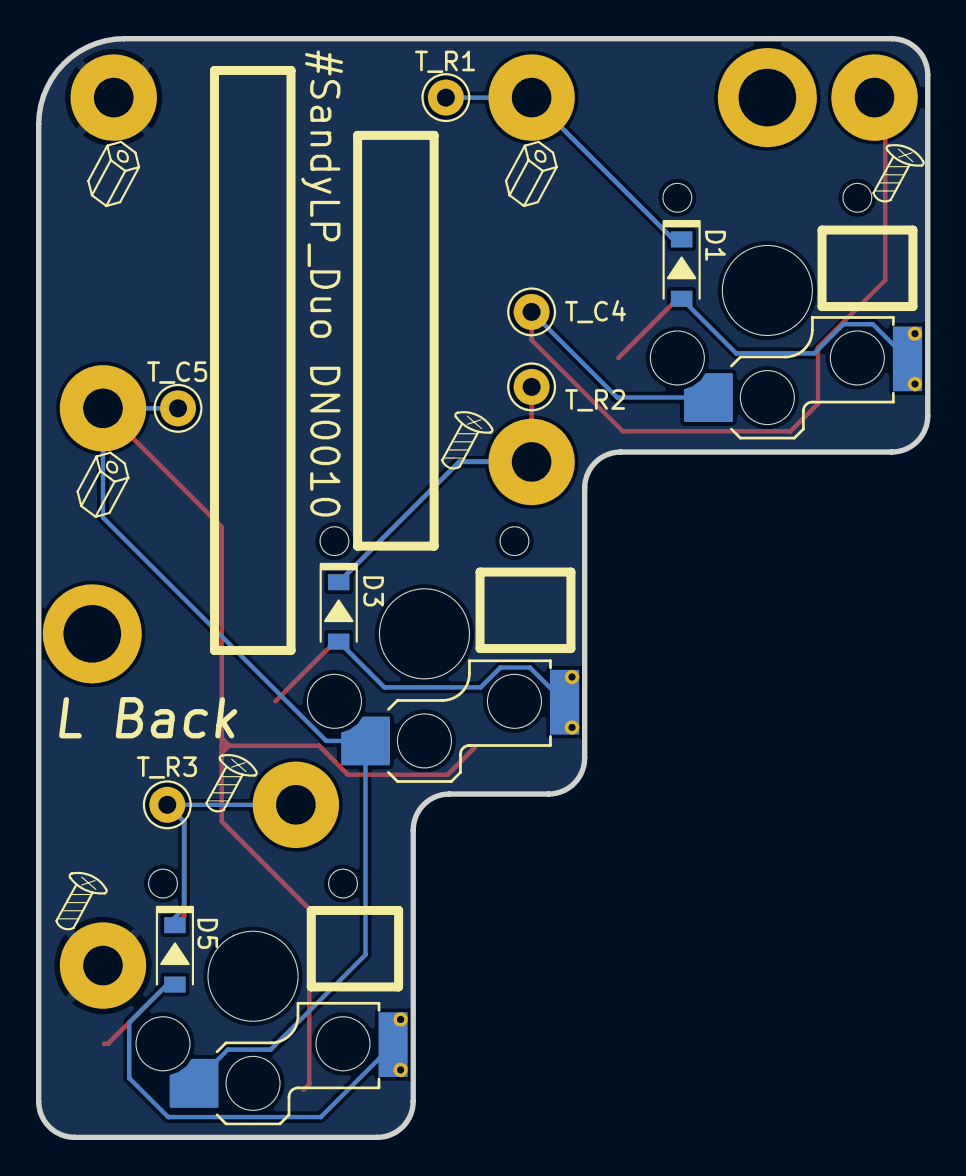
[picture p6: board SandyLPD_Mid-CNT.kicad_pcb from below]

Board: 2 copper layers, 49.4 x 61.0 mm, 27 parts (11 on the bottom side), 12 nets.

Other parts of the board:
Cutout1: 60_Outline; SandyLPD_outline_Mid-CNT

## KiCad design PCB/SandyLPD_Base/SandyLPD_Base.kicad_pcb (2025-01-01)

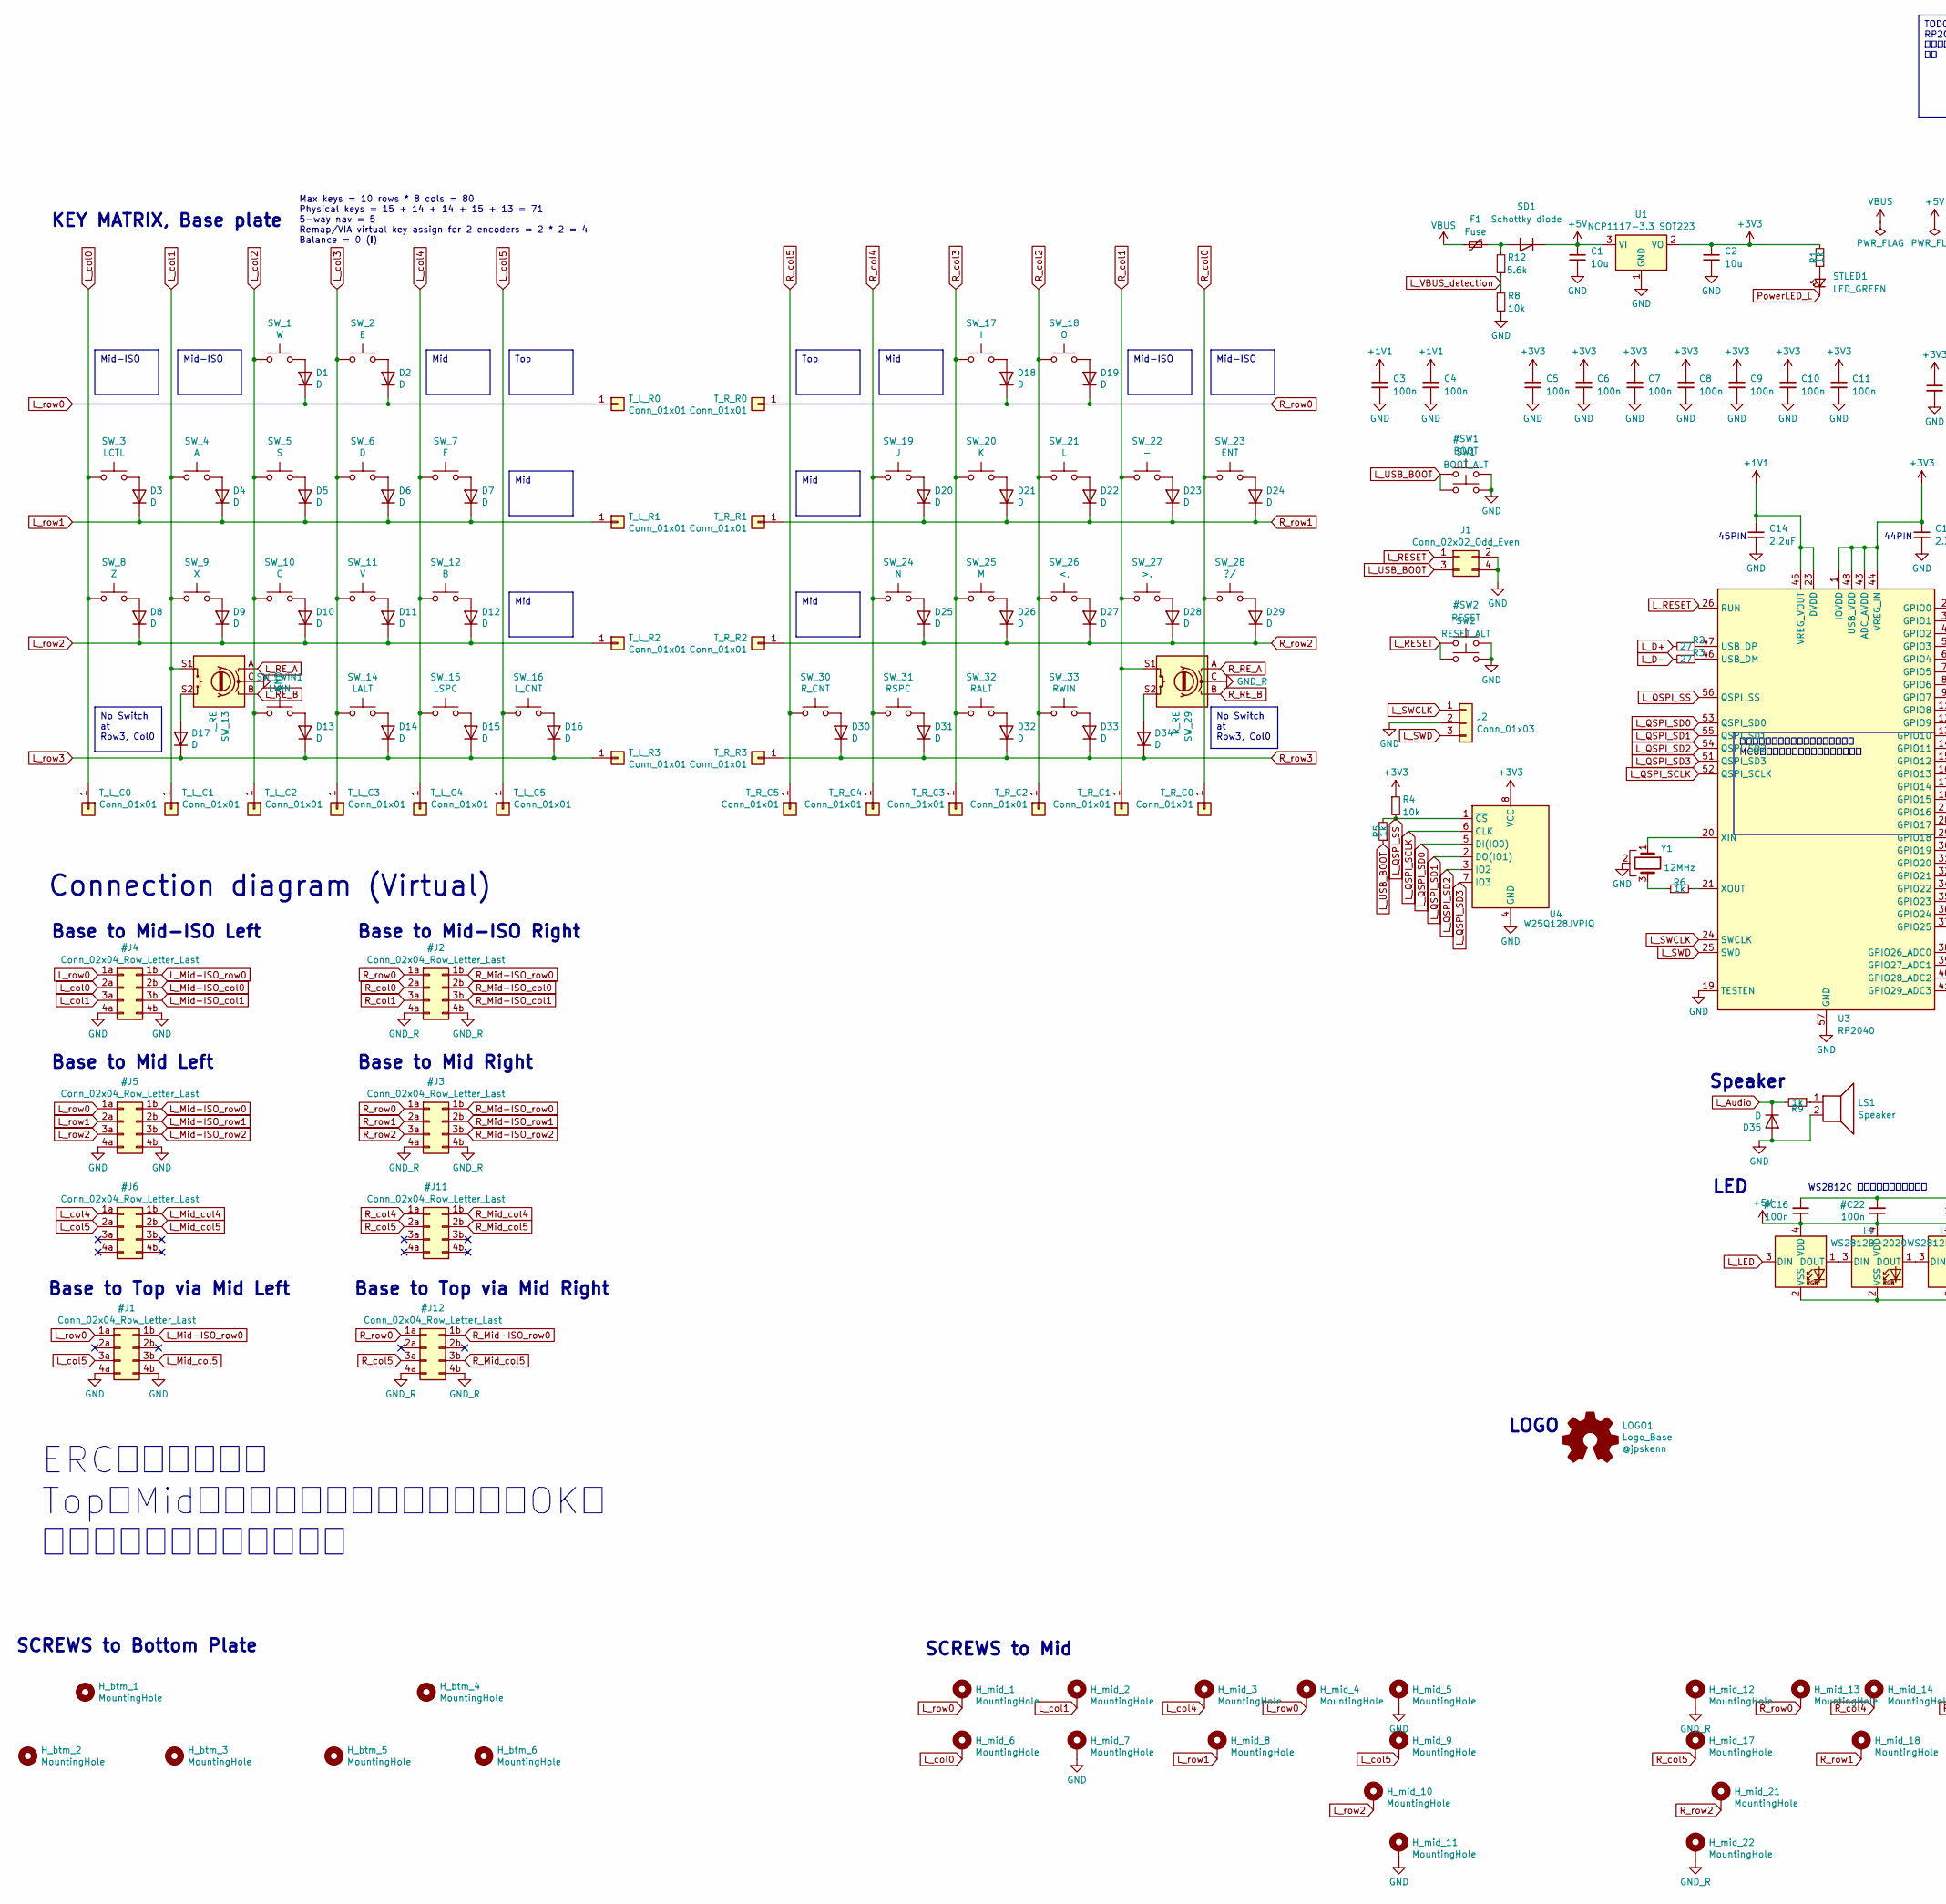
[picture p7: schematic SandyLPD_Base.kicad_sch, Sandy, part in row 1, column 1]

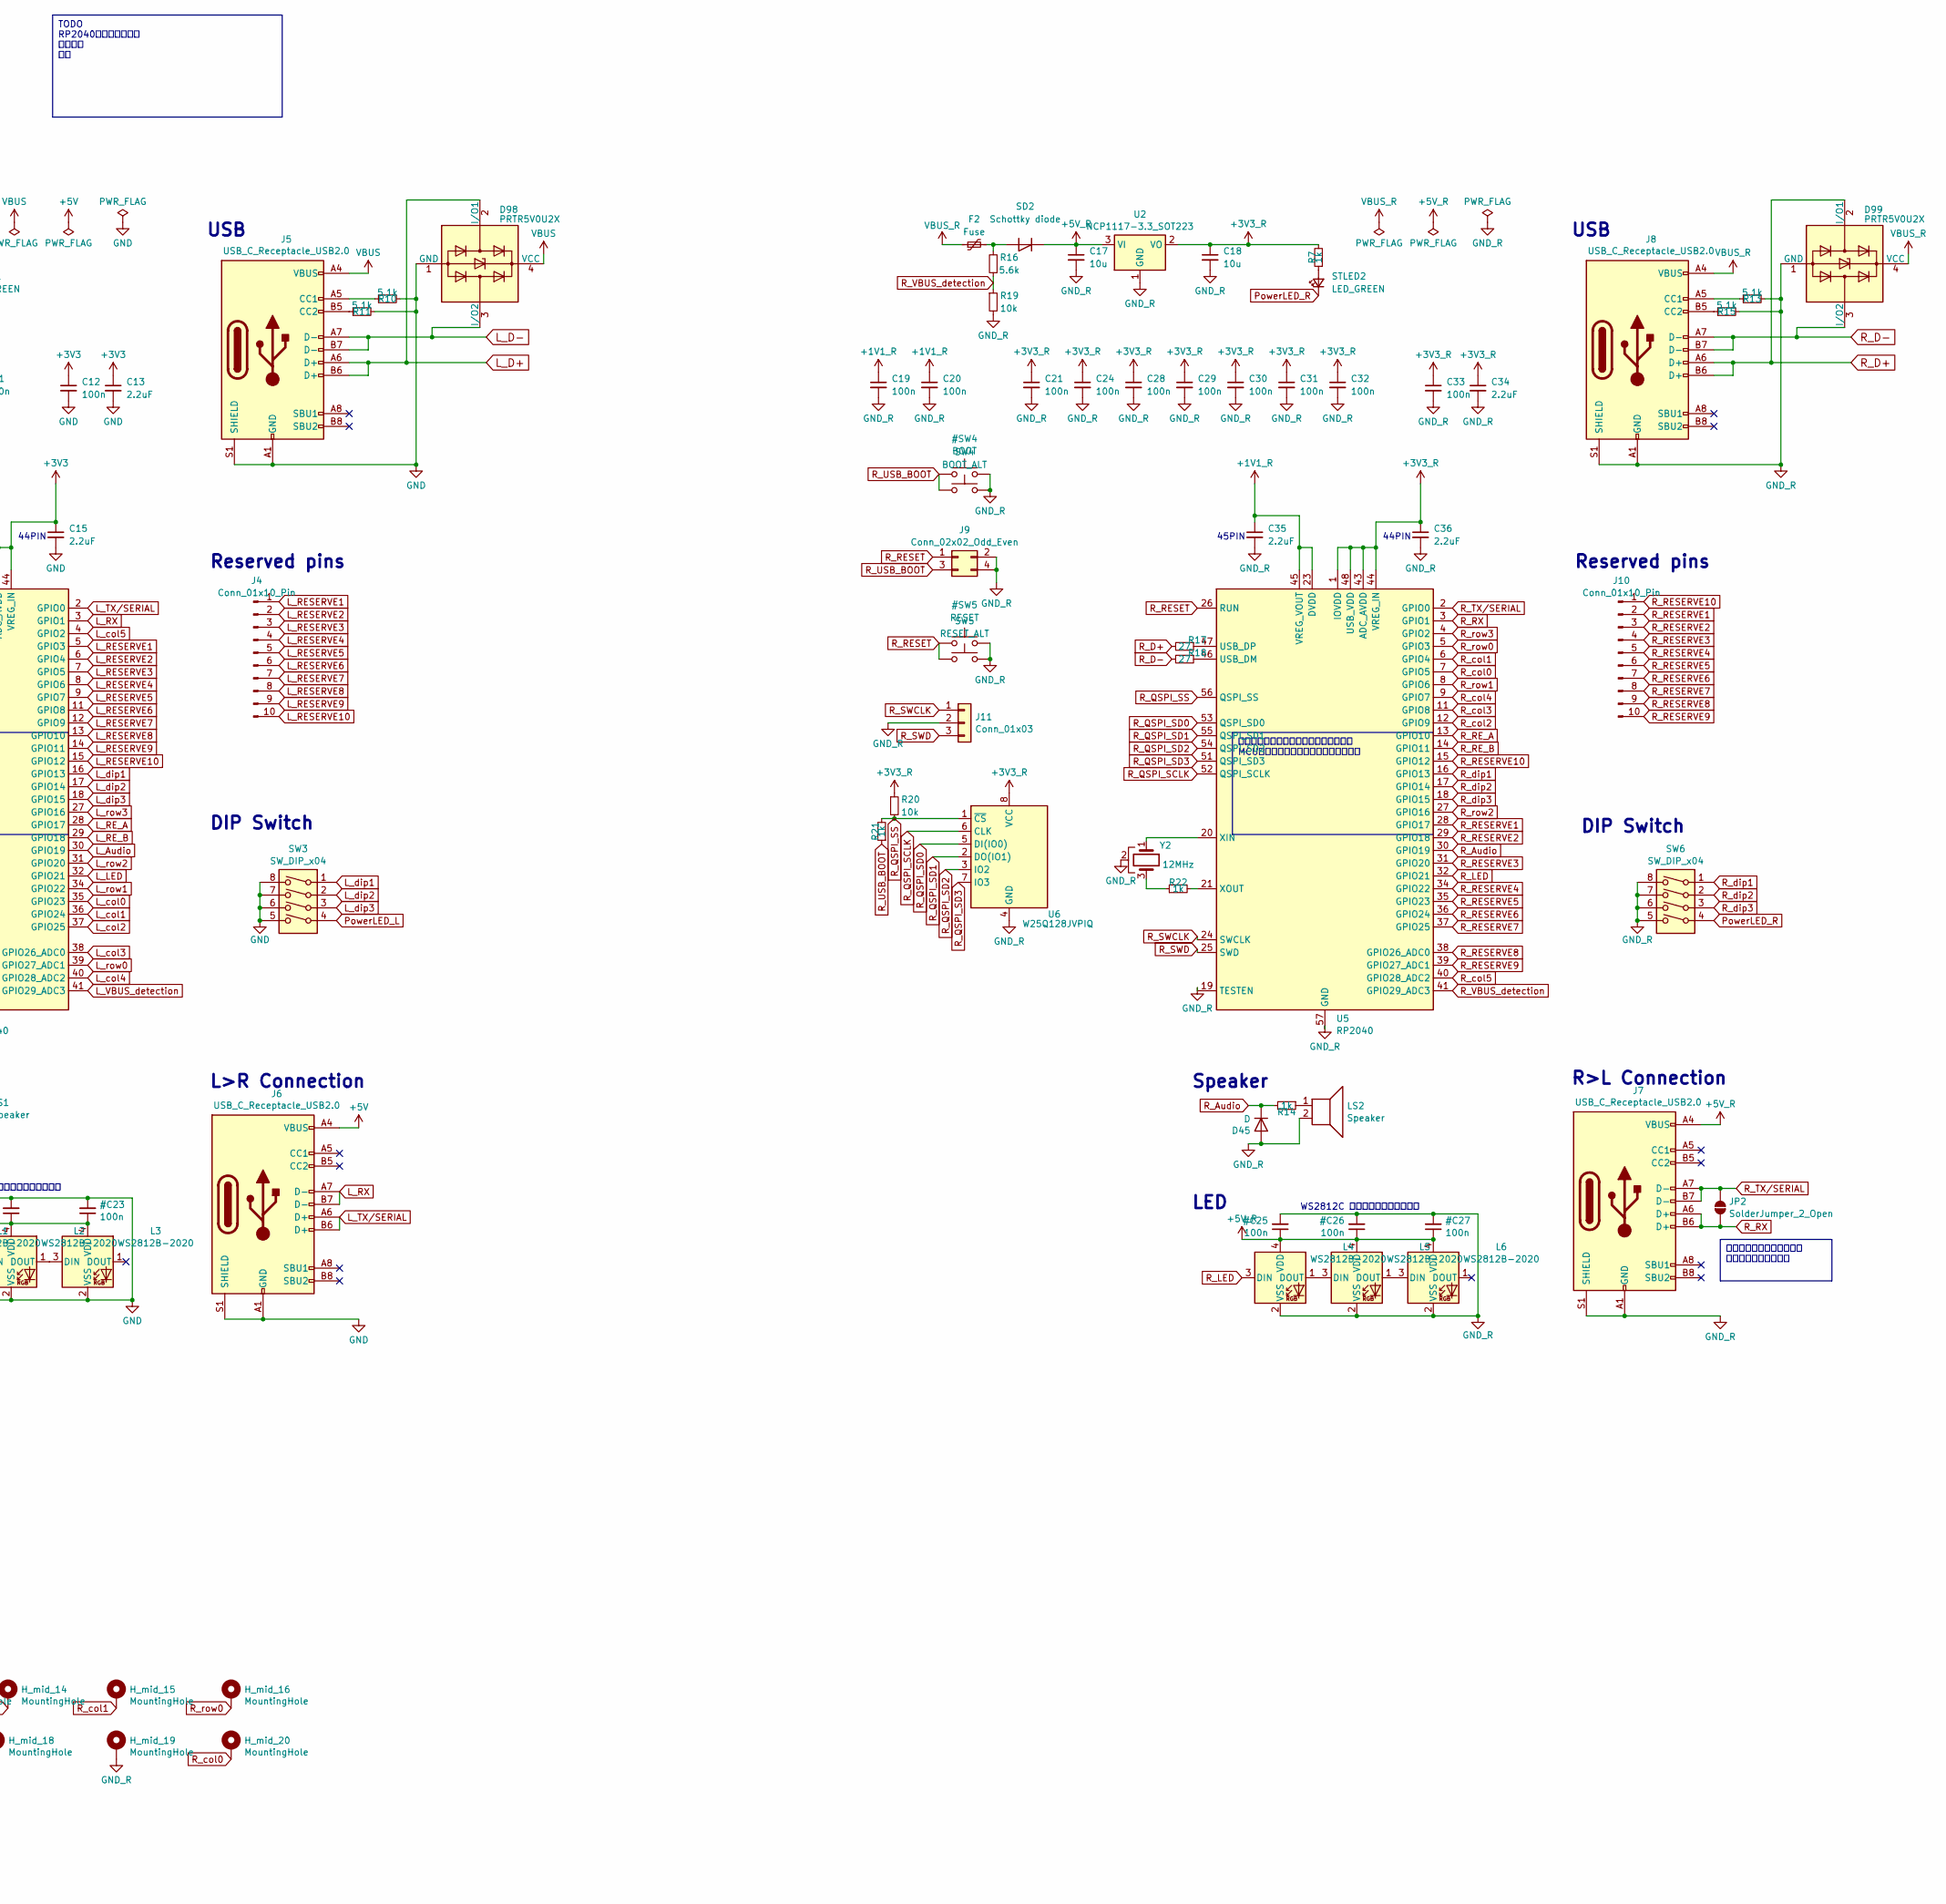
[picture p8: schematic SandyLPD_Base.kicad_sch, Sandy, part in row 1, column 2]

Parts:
C1, C2, C17, C18: 10u; C_0805_2012Metric; LCSC C15850
C3, C4, C5, C6, C7, C8, C9, C10, C11, C12, C19, C20, C21, C24, C28, C29, C30, C31, C32, C33: 100n; C_0402_1005Metric; LCSC C1525
C13, C14, C15, C34, C35, C36: 2.2uF; C_0402_1005Metric; LCSC C307418
D1, D2, D3, D4, D5, D6, D7, D8, D9, D10, D11, D12, D13, D14, D15, D16, D17, D18, D19, D20, D21, D22, D23, D24, D25, D26, D27, D28, D29, D30, D31, D32, D33, D34, D35, D45: D; D_SOD-123_Emphasized_Direction_Line_Reference_on_bottom; LCSC C81598
D98, D99: PRTR5V0U2X; SOT-143; LCSC C78442
F1, F2: Fuse; Fuse_0603_1608Metric; LCSC C187605
H_btm_1, H_btm_2, H_btm_3, H_btm_4, H_btm_5, H_btm_6: MountingHole; MountingHole_M2_Through-hole_tap_THC-0.8-x-2
H_mid_1, H_mid_2, H_mid_3, H_mid_4, H_mid_5, H_mid_6, H_mid_7, H_mid_8, H_mid_9, H_mid_10, H_mid_11, H_mid_12, H_mid_13, H_mid_14, H_mid_15, H_mid_16, H_mid_17, H_mid_18, H_mid_19, H_mid_20, H_mid_21, H_mid_22: MountingHole; MountingHole_M2_Through-hole_tap_THC-0.8-x-2
J1, J9: Conn_02x02_Odd_Even; PinHeader_2x02_P2.00mm_Vertical_2pair
J2, J11: Conn_01x03; PinHeader_1x03_P2.54mm_Vertical_All_circle
J4, J10: Conn_01x10_Pin; PinHeader_1x10_P1.00mm_Vertical
J5, J6, J7, J8: USB_C_Receptacle_USB2.0; USB_C_Receptacle_HRO_TYPE-C-31-M-12; LCSC C165948
JP2: SolderJumper_2_Open; SolderJumper-2_P1.3mm_Open_RoundedPad1.0x1.5mm
L1, L2, L3, L4, L5, L6: WS2812B-2020; LED_WS2812B-2020_PLCC4_2.0x2.0mm
LOGO1: Logo_Base; SandyLP_logo_LP40_w60
LS1, LS2: Speaker; Buzzer_Murata_PKMCS0909E; LCSC-Reserve C910763
R1, R5, R6, R7, R9, R14, R21, R22: 1k; R_0402_1005Metric; LCSC C11702
R2, R3, R17, R18: 27; R_0402_1005Metric; LCSC C25100
R4, R8, R19, R20: 10k; R_0402_1005Metric; LCSC C25744
R10, R11, R13, R15: 5.1k; R_0402_1005Metric; LCSC C25905
R12, R16: 5.6k; R_0402_1005Metric; LCSC C25905
SD1, SD2: Schottky diode; D_SOD-123; LCSC C8598
STLED1, STLED2: LED_GREEN; LED_0805_2012Metric; LCSC C2297
SW1, SW4: BOOT_ALT; SW_SPST_PTS810; LCSC-Reserve C116501
SW2, SW5: RESET_ALT; SW_SPST_PTS810; LCSC-Reserve C116501
SW3, SW6: SW_DIP_x04; SW_DIP_SPSTx04_Slide_Copal_CHS-04B_W7.62mm_P1.27mm
SW_1: W; Kailh_socket_ChocV2
SW_2: E; Kailh_socket_ChocV2
SW_3: LCTL; Kailh_socket_ChocV2
SW_4: A; Kailh_socket_ChocV2
SW_5: S; Kailh_socket_ChocV2
SW_6: D; Kailh_socket_ChocV2
SW_7: F; Kailh_socket_ChocV2
SW_8: Z; Kailh_socket_ChocV2
SW_9: X; Kailh_socket_ChocV2
SW_10: C; Kailh_socket_ChocV2
SW_11: V; Kailh_socket_ChocV2
SW_12: B; Kailh_socket_ChocV2
SW_13: L_RE; ChocV2_AND_RotaryEncoder_Alps_EC11E-Switch_Vertical_H20mm_N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
SW_14: LALT; Kailh_socket_ChocV2
SW_15: LSPC; Kailh_socket_ChocV2
SW_16: L_CNT; Kailh_socket_ChocV2
SW_17: I; Kailh_socket_ChocV2
SW_18: O; Kailh_socket_ChocV2
SW_19: J; Kailh_socket_ChocV2
SW_20: K; Kailh_socket_ChocV2
SW_21: L; Kailh_socket_ChocV2
SW_22: -; Kailh_socket_ChocV2
SW_23: ENT; Kailh_socket_ChocV2
SW_24: N; Kailh_socket_ChocV2
SW_25: M; Kailh_socket_ChocV2
SW_26: <,; Kailh_socket_ChocV2
SW_27: >.; Kailh_socket_ChocV2
SW_28: ?/; Kailh_socket_ChocV2
SW_29: R_RE; ChocV2_AND_RotaryEncoder_Alps_EC11E-Switch_Vertical_H20mm_N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
SW_30: R_CNT; Kailh_socket_ChocV2
SW_31: RSPC; Kailh_socket_ChocV2
SW_32: RALT; Kailh_socket_ChocV2
SW_33: RWIN; Kailh_socket_ChocV2
SW_LWIN1: LWIN; Kailh_socket_ChocV2
T_L_C0, T_L_C1, T_L_C2, T_L_C3, T_L_C4, T_L_C5: Conn_01x01; TestPoint_THTPad_D2.0mm_Drill1.0mm
T_L_R0, T_L_R1, T_L_R2, T_L_R3: Conn_01x01; TestPoint_THTPad_D2.0mm_Drill1.0mm
T_R_C0, T_R_C1, T_R_C2, T_R_C3, T_R_C4, T_R_C5: Conn_01x01; TestPoint_THTPad_D2.0mm_Drill1.0mm
T_R_R0, T_R_R1, T_R_R2, T_R_R3: Conn_01x01; TestPoint_THTPad_D2.0mm_Drill1.0mm
U1, U2: NCP1117-3.3_SOT223; SOT-223-3_TabPin2; LCSC C347222
U3, U5: RP2040; RP2040-QFN-56; LCSC C2040
U4, U6: W25Q128JVPIQ; WSON-8-1EP_6x5mm_P1.27mm_EP3.4x4.3mm; LCSC C190862
Y1, Y2: 12MHz; Resonator_SMD_Murata_CSTxExxV-3Pin_3.0x1.1mm; MFR.Part # CSTNE12M0G550000R0; LCSC C341520

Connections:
+1V1: C3.1, C4.1, C14.1, U3.23 (DVDD), U3.45 (VREG_VOUT), U3.50 (DVDD)
+1V1_R: C19.1, C20.1, C35.1, U5.23 (DVDD), U5.45 (VREG_VOUT), U5.50 (DVDD)
+3V3: C2.1, C5.1, C6.1, C7.1, C8.1, C9.1, C10.1, C11.1, C12.1, C13.1, C15.1, R1.2, R4.1, U1.2 (VO), U3.1 (IOVDD), U3.10 (IOVDD), U3.22 (IOVDD), U3.33 (IOVDD), U3.42 (IOVDD), U3.43 (ADC_AVDD), U3.44 (VREG_IN), U3.48 (USB_VDD), U3.49 (IOVDD), U4.8 (VCC)
+3V3_R: C18.1, C21.1, C24.1, C28.1, C29.1, C30.1, C31.1, C32.1, C33.1, C34.1, C36.1, R7.2, R20.1, U2.2 (VO), U5.1 (IOVDD), U5.10 (IOVDD), U5.22 (IOVDD), U5.33 (IOVDD), U5.42 (IOVDD), U5.43 (ADC_AVDD), U5.44 (VREG_IN), U5.48 (USB_VDD), U5.49 (IOVDD), U6.8 (VCC)
L_Audio: D35.1 (K), R9.2, U3.30 (GPIO19)
L_D+: D98.2 (I/O1), J5.A6 (D+), J5.B6 (D+), R2.2
L_D-: D98.3 (I/O2), J5.A7 (D-), J5.B7 (D-), R3.2
L_LED: L1.3 (DIN), U3.32 (GPIO21)
L_QSPI_SCLK: U3.52 (QSPI_SCLK), U4.6 (CLK)
L_QSPI_SD0: U3.53 (QSPI_SD0), U4.5 (DI(IO0))
L_QSPI_SD1: U3.55 (QSPI_SD1), U4.2 (DO(IO1))
L_QSPI_SD2: U3.54 (QSPI_SD2), U4.3 (IO2)
L_QSPI_SD3: U3.51 (QSPI_SD3), U4.7 (IO3)
L_QSPI_SS: R4.2, R5.2, U3.56 (QSPI_SS), U4.1 (~CS)
L_RESERVE1: J4.1, U3.5 (GPIO3)
L_RESERVE2: J4.2, U3.6 (GPIO4)
L_RESERVE3: J4.3, U3.7 (GPIO5)
L_RESERVE4: J4.4, U3.8 (GPIO6)
L_RESERVE5: J4.5, U3.9 (GPIO7)
L_RESERVE6: J4.6, U3.11 (GPIO8)
L_RESERVE7: J4.7, U3.12 (GPIO9)
L_RESERVE8: J4.8, U3.13 (GPIO10)
L_RESERVE9: J4.9, U3.14 (GPIO11)
L_RESERVE10: J4.10, U3.15 (GPIO12)
L_RE_A: SW_13.A, U3.28 (GPIO17)
L_RE_B: SW_13.B, U3.29 (GPIO18)
L_RX: J6.A7 (D-), J6.B7 (D-), U3.3 (GPIO1)
L_SWCLK: J2.1, U3.24 (SWCLK)
L_SWD: J2.3, U3.25 (SWD)
L_TX/SERIAL: J6.A6 (D+), J6.B6 (D+), U3.2 (GPIO0)
L_VBUS_detection: R8.1, R12.1, U3.41 (GPIO29_ADC3)
L_col2: SW_1.1, SW_5.1, SW_10.1, SW_LWIN1.1, T_L_C2.1, U3.37 (GPIO25)
L_col3: SW_2.1, SW_6.1, SW_11.1, SW_14.1, T_L_C3.1, U3.38 (GPIO26_ADC0)
L_dip1: SW3.1, U3.16 (GPIO13)
L_dip2: SW3.2, U3.17 (GPIO14)
L_dip3: SW3.3, U3.18 (GPIO15)
L_row3: D13.1 (K), D14.1 (K), D15.1 (K), D16.1 (K), D17.1 (K), T_L_R3.1, U3.27 (GPIO16)
unnamed: D1.2 (A), SW_1.2
unnamed: D2.2 (A), SW_2.2
unnamed: D3.2 (A), SW_3.2
unnamed: D4.2 (A), SW_4.2
unnamed: D5.2 (A), SW_5.2
unnamed: D6.2 (A), SW_6.2
unnamed: D7.2 (A), SW_7.2
unnamed: D8.2 (A), SW_8.2
unnamed: D9.2 (A), SW_9.2
unnamed: D10.2 (A), SW_10.2
unnamed: D11.2 (A), SW_11.2
unnamed: D12.2 (A), SW_12.2
unnamed: D13.2 (A), SW_LWIN1.2
unnamed: D14.2 (A), SW_14.2
unnamed: D15.2 (A), SW_15.2
unnamed: D16.2 (A), SW_16.2
unnamed: D17.2 (A), SW_13.S2
unnamed: D18.2 (A), SW_17.2
unnamed: D19.2 (A), SW_18.2
unnamed: D20.2 (A), SW_19.2
unnamed: D21.2 (A), SW_20.2
unnamed: D22.2 (A), SW_21.2
unnamed: D23.2 (A), SW_22.2
unnamed: D24.2 (A), SW_23.2
unnamed: D25.2 (A), SW_24.2
unnamed: D26.2 (A), SW_25.2
unnamed: D27.2 (A), SW_26.2
unnamed: D28.2 (A), SW_27.2
unnamed: D29.2 (A), SW_28.2
unnamed: D30.2 (A), SW_30.2
unnamed: D31.2 (A), SW_31.2
unnamed: D32.2 (A), SW_32.2
unnamed: D33.2 (A), SW_33.2
unnamed: D34.2 (A), SW_29.S2
unnamed: J5.A5 (CC1), R10.1
unnamed: J5.B5 (CC2), R11.1
unnamed: J8.A5 (CC1), R13.1
unnamed: J8.B5 (CC2), R15.1
unnamed: L1.1 (DOUT), L2.3 (DIN)
unnamed: L2.1 (DOUT), L3.3 (DIN)
unnamed: L4.1 (DOUT), L5.3 (DIN)
unnamed: L5.1 (DOUT), L6.3 (DIN)
unnamed: LS1.1, R9.1
unnamed: LS2.1, R14.1
unnamed: R6.1, Y1.3
unnamed: R22.1, Y2.3
unnamed: F1.2, R12.2, SD1.2 (A)
unnamed: F2.2, R16.2, SD2.2 (A)
unnamed: R1.1, STLED1.2 (A)
unnamed: R7.1, STLED2.2 (A)
unnamed: R3.1, U3.46 (USB_DM)
unnamed: R2.1, U3.47 (USB_DP)
unnamed: U3.20 (XIN), Y1.1
unnamed: R6.2, U3.21 (XOUT)
unnamed: R18.1, U5.46 (USB_DM)
unnamed: R17.1, U5.47 (USB_DP)
unnamed: U5.20 (XIN), Y2.1
unnamed: R22.2, U5.21 (XOUT)
PowerLED_L: STLED1.1 (K), SW3.4
PowerLED_R: STLED2.1 (K), SW6.4
R_Audio: D45.1 (K), R14.2, U5.30 (GPIO19)
R_D+: D99.2 (I/O1), J8.A6 (D+), J8.B6 (D+), R17.2
R_D-: D99.3 (I/O2), J8.A7 (D-), J8.B7 (D-), R18.2
R_LED: L4.3 (DIN), U5.32 (GPIO21)
R_QSPI_SCLK: U5.52 (QSPI_SCLK), U6.6 (CLK)
R_QSPI_SD0: U5.53 (QSPI_SD0), U6.5 (DI(IO0))
R_QSPI_SD1: U5.55 (QSPI_SD1), U6.2 (DO(IO1))
R_QSPI_SD2: U5.54 (QSPI_SD2), U6.3 (IO2)
R_QSPI_SD3: U5.51 (QSPI_SD3), U6.7 (IO3)
R_QSPI_SS: R20.2, R21.2, U5.56 (QSPI_SS), U6.1 (~CS)
R_RESERVE1: J10.2, U5.28 (GPIO17)
R_RESERVE2: J10.3, U5.29 (GPIO18)
R_RESERVE3: J10.4, U5.31 (GPIO20)
R_RESERVE4: J10.5, U5.34 (GPIO22)
R_RESERVE5: J10.6, U5.35 (GPIO23)
R_RESERVE6: J10.7, U5.36 (GPIO24)
R_RESERVE7: J10.8, U5.37 (GPIO25)
R_RESERVE8: J10.9, U5.38 (GPIO26_ADC0)
R_RESERVE9: J10.10, U5.39 (GPIO27_ADC1)
R_RESERVE10: J10.1, U5.15 (GPIO12)
R_RE_A: SW_29.A, U5.13 (GPIO10)
R_RE_B: SW_29.B, U5.14 (GPIO11)
R_RX: J7.A6 (D+), J7.B6 (D+), JP2.1 (A), U5.3 (GPIO1)
R_SWCLK: J11.1, U5.24 (SWCLK)
R_SWD: J11.3, U5.25 (SWD)
R_TX/SERIAL: J7.A7 (D-), J7.B7 (D-), JP2.2 (B), U5.2 (GPIO0)
R_VBUS_detection: R16.1, R19.1, U5.41 (GPIO29_ADC3)
R_col2: SW_18.1, SW_21.1, SW_26.1, SW_33.1, T_R_C2.1, U5.12 (GPIO9)
R_col3: SW_17.1, SW_20.1, SW_25.1, SW_32.1, T_R_C3.1, U5.11 (GPIO8)
R_dip1: SW6.1, U5.16 (GPIO13)
R_dip2: SW6.2, U5.17 (GPIO14)
R_dip3: SW6.3, U5.18 (GPIO15)
R_row3: D30.1 (K), D31.1 (K), D32.1 (K), D33.1 (K), D34.1 (K), T_R_R3.1, U5.4 (GPIO2)
VBUS: D98.4 (VCC), F1.1, J5.A4 (VBUS), J5.A9 (VBUS), J5.B4 (VBUS), J5.B9 (VBUS)
VBUS_R: D99.4 (VCC), F2.1, J8.A4 (VBUS), J8.A9 (VBUS), J8.B4 (VBUS), J8.B9 (VBUS)

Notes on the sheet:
No Switch at Row3, Col0
Mid
ピンはとりあえず仮に配置してるだけ。 MCUを基板に配置後、最適化する予定。
Mid-ISO
TODO RP2040まわりの右手側 仮想接続 ネジ
Top
全二重はジャンパをしない 半二重はジャンパする
R>L Connection
Base to Top via Mid Left
WS2812C バイパスコンデンサ不要
SCREWS to Mid
L>R Connection
SCREWS to Bottom Plate
Speaker
USB
Base to Top via Mid Right
Connection diagram (Virtual)
Base to Mid-ISO Right
44PIN
LOGO
45PIN
Base to Mid Right
Reserved pins
Base to Mid-ISO Left
LED
ERCチェックで、 TopとMidのラベルが見つからないのはOK。 （別プロジェクトでやる）
KEY MATRIX, Base plate
Base to Mid Left
DIP Switch
Max keys = 10 rows * 8 cols = 80 Physical keys = 15 + 14 + 14 + 15 + 13 = 71 5-way nav = 5 Remap/VIA virtual key assign for 2 encoders = 2 * 2 = 4 Balance = 0 (!)

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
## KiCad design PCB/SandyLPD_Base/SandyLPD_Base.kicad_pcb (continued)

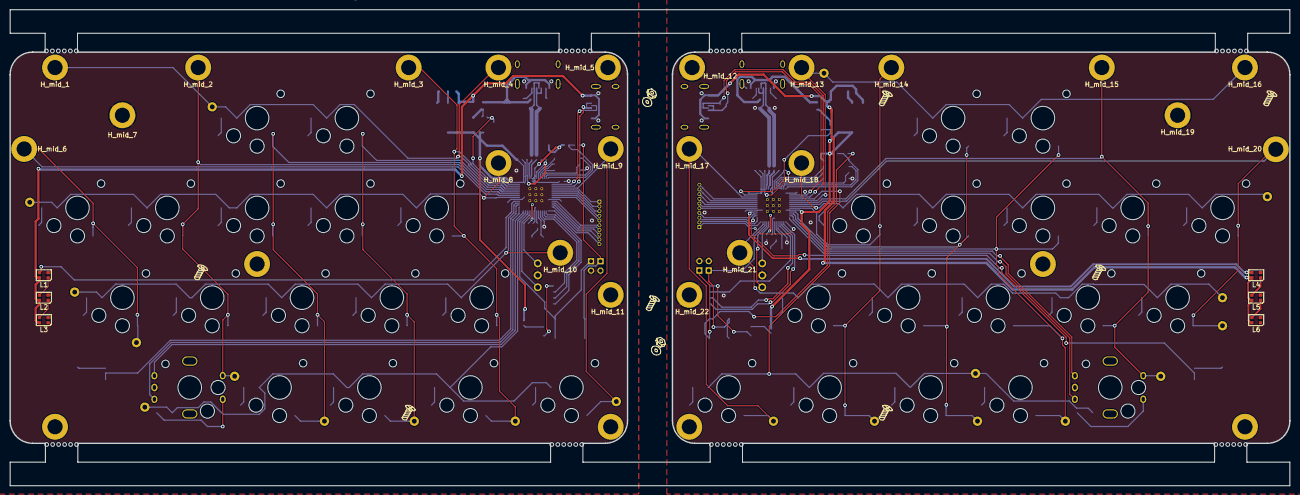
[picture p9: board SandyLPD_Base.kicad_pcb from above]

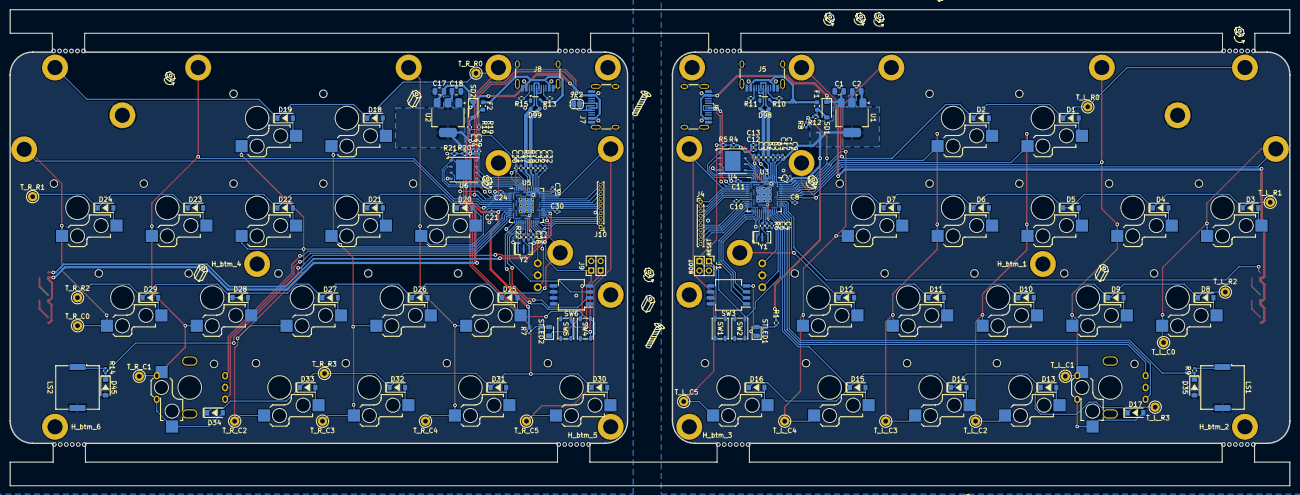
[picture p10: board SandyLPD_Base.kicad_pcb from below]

Board: 2 copper layers, 271.5 x 101.0 mm, 212 parts (149 on the bottom side), 154 nets.

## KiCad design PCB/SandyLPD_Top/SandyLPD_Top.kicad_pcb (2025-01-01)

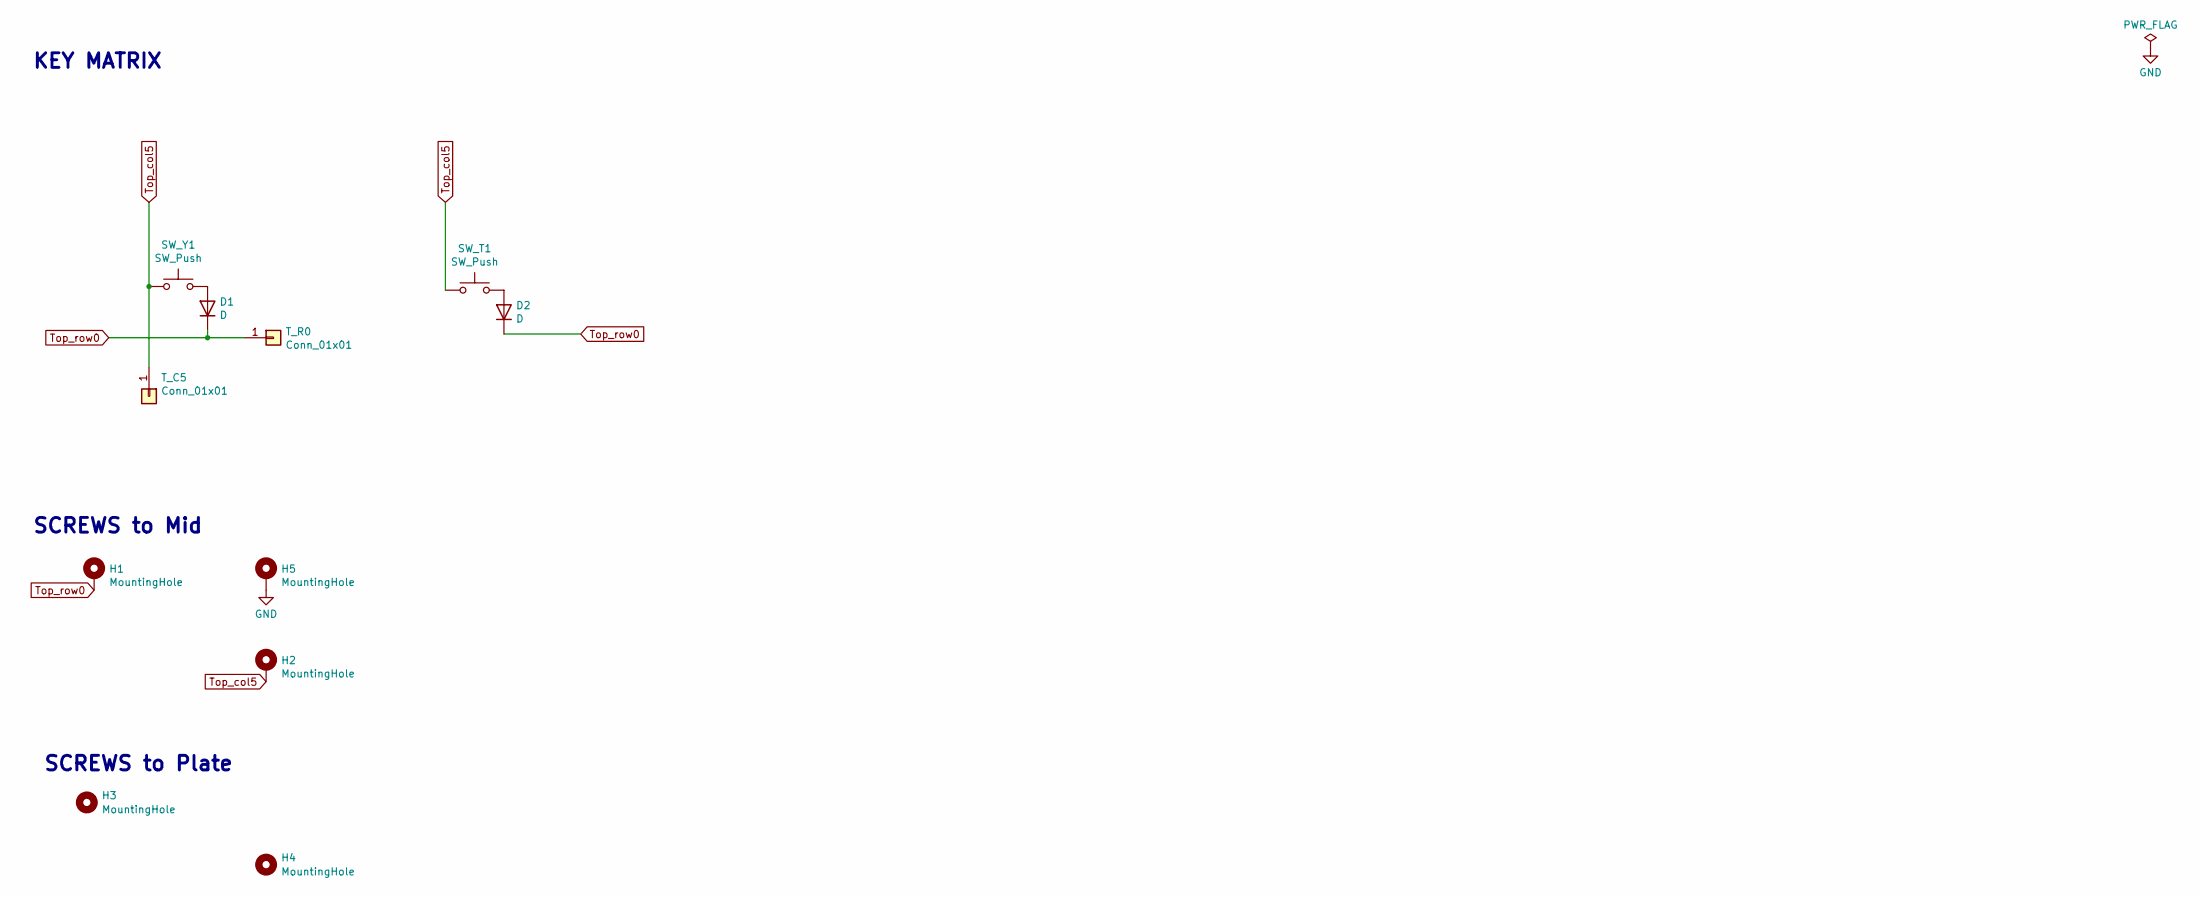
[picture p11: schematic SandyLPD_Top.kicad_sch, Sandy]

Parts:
D1, D2: D; D_SOD-123_Emphasized_Direction_Line; LCSC C81598
H1, H2, H5: MountingHole; MountingHole_2.2mm_M2_Pad_minimal
H3, H4: MountingHole; MountingHole_M2_Through-hole_tap_THC-0.8-x-2
SW_T1: SW_Push; Kailh_socket_ChocV2_for_Reverse
SW_Y1: SW_Push; Kailh_socket_ChocV2_small_#2pad_for_Reverse_no_hole
T_C5: Conn_01x01; TestPoint_THTPad_D2.0mm_Drill1.0mm
T_R0: Conn_01x01; TestPoint_THTPad_D2.0mm_Drill1.0mm

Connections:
GND: H5.1
unnamed: D1.2 (A), SW_Y1.2
unnamed: D2.2 (A), SW_T1.2
Top_col5: H2.1, SW_T1.1, SW_Y1.1, T_C5.1
Top_row0: D1.1 (K), D2.1 (K), H1.1, T_R0.1

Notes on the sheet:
SCREWS to Plate
KEY MATRIX
SCREWS to Mid

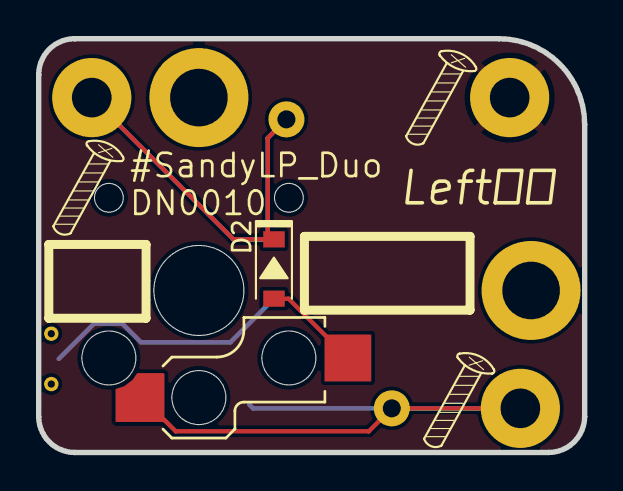
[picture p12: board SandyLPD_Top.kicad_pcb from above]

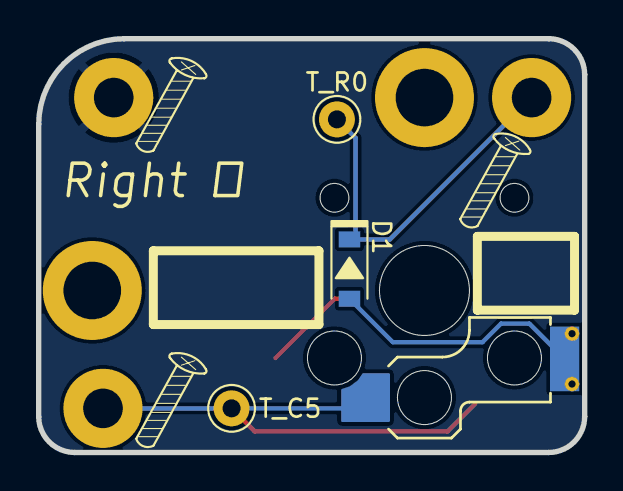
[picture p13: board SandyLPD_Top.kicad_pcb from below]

Board: 2 copper layers, 30.3 x 23.0 mm, 11 parts (4 on the bottom side), 4 nets.

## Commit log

2024-12-11 SandyLPを元に書き始めた
2024-12-12 SandyLPからBaseをコピー。RP2040-Zeroテスト中。
    [LED_SK6812MINI-E.step, SandyLPD_Base.kicad_pcb, SandyLPD_Base.kicad_sch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]
2024-12-12 TRRSジャック確認
    [SandyLPD_Base.kicad_pcb]
2024-12-14 TRRSとRP2040-Zeroを追加
2024-12-14 回路図作成中。RP2040-Zero等不要ファイル削除。
    [SandyLPD_Base.kicad_pcb, SandyLPD_Base.kicad_sch]
2024-12-14 Base基板 ネジ穴仮配置
    [SandyLPD_Base.kicad_pcb, SandyLPD_Base.kicad_sch]
2024-12-15 Base基板 MCUまわりの配置検討
    [SandyLPD_Base.kicad_pcb, SandyLPD_Base.kicad_sch]
2024-12-16 スルーホールタップ等を盛り込み
2024-12-16 ネジ位置調整中
    [SandyLPD_Base.kicad_pcb, SandyLPD_Base.kicad_sch]
2024-12-19 スルーホールタップ位置確認。Base基板外形を左右へ拡大。
    [SandyLPD_Base.kicad_pcb]
2024-12-19 ネジ位置決定のつもり
    [SandyLPD_Base.kicad_pcb, SandyLPD_Base.kicad_sch]
2024-12-19 とりあえずMCUまわりに配線できることを確認
    [SandyLPD_Base.kicad_sch]
2024-12-20 MCU使用ピンを仮決め中
    [SandyLPD_Base.kicad_sch]
2024-12-20 フラッシュメモリの部品置き換わりを修正
    [SandyLPD_Base.kicad_sch]
2024-12-20 仮配線中
    [SandyLPD_Base.kicad_sch]
2024-12-20 ボトムプレートの穴あけに向け、パーツ位置調整中。
2024-12-21 LED、WS2812Cはパスコン不要のため、仮想パーツとして実際には配置しない。
    [SandyLPD_Base.kicad_sch]
2024-12-21 パーツ配置調整中
    [SandyLPD_Base.kicad_sch]
2024-12-21 左手のパーツ配置と配線、一旦完了。
    [SandyLPD_Base.kicad_sch]
2024-12-21 ボトムA作成
    [LED_SK6812MINI-E.step, SandyLPD_Plate_BottomA.kicad_pcb, SandyLPD_Plate_BottomA.kicad_sch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]
2024-12-21 基板外側のボトム用ネジ位置を変更 #18
    [SandyLPD_Base.kicad_pcb, SandyLPD_Plate_BottomA.kicad_pcb]
2024-12-21 ボトムプレートB追加
    [LED_SK6812MINI-E.step, SandyLPD_Plate_BottomB.kicad_pcb, SandyLPD_Plate_BottomB.kicad_sch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]
2024-12-21 ボトムプレートの左右幅調整 #18
    [SandyLPD_Plate_BottomA.kicad_pcb, SandyLPD_Plate_BottomB.kicad_pcb]
2024-12-22 Mid-ISO追加
    [SandyLPD_Mid-ISO-B_Cu.gbl, SandyLPD_Mid-ISO-B_Fab.gbr, SandyLPD_Mid-ISO-B_Mask.gbs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]
2024-12-22 Mid中央追加。調整中。外形なども含めまだまだ。
    [SandyLPD_Mid-CNT-B_Cu.gbl, SandyLPD_Mid-CNT-B_Fab.gbr, SandyLPD_Mid-CNT-B_Mask.gbs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]
2024-12-22 Base→MId中央のネジ位置を1箇所変更
    Mid中央をリバーシブルにすると、ソケットのパッドと干渉が出たため。
    [SandyLPD_Base.kicad_pcb, SandyLPD_Mid-CNT.kicad_pcb, SandyLPD_Mid-CNT.kicad_sch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]
2024-12-22 Mid中央プレート用のネジ穴位置調整
    [SandyLPD_Base.kicad_pcb]
2024-12-22 Mid中央、配線やシルク調整中。
    [SandyLPD_Mid-CNT.kicad_pcb, SandyLPD_Mid-CNT.kicad_sch]
2024-12-22 未使用ファイル削除
2024-12-22 パーツ配置完了。ネジ位置調整中。
    [SandyLPD_Mid-CNT.kicad_pcb, SandyLPD_Mid-CNT.kicad_sch]
2024-12-22 スルーホールタップの接続先を変更・調整 #19
    [SandyLPD_Base.kicad_pcb, SandyLPD_Mid-CNT.kicad_pcb, SandyLPD_Mid-CNT.kicad_sch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]
2024-12-22 不要ファイル削除
2024-12-22 Top基板追加
    [SandyLPD_Top-B_Cu.gbl, SandyLPD_Top-B_Fab.gbr, SandyLPD_Top-B_Mask.gbs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]
2024-12-22 シルク調整
    [SandyLPD_Mid-ISO.kicad_pcb]
2024-12-22 Mid-ISO用スイッチプレート追加
    [SandyLPD_Plate_Mid_ISO-B_Cu.gbl, SandyLPD_Plate_Mid_ISO-B_Fab.gbr, SandyLPD_Plate_Mid_ISO-B_Mask.gbs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]
2024-12-22 Top用スイッチプレート追加
    [SandyLPD_Plate_Top-B_Cu.gbl, SandyLPD_Plate_Top-B_Fab.gbr, SandyLPD_Plate_Top-B_Mask.gbs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]
2024-12-22 不要コメント削除
    [SandyLPD_Plate_Mid_ISO.kicad_sch]
2024-12-22 WIP Mid-CNT用スイッチプレート追加。穴サイズ調整中。
    [SandyLPD_Plate_Mid-CNT-B_Cu.gbl, SandyLPD_Plate_Mid-CNT-B_Fab.gbr, SandyLPD_Plate_Mid-CNT-B_Mask.gbs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]
2024-12-22 WIP Top基板裏側のソケットを逃す穴を作成中。
    [SandyLPD_Plate_Mid-CNT.kicad_pcb, SandyLPD_Plate_Mid-CNT.kicad_sch]
2024-12-22 WIP Top基板うら側のソケットを逃がす穴に調整中
    [SandyLPD_Plate_Mid-CNT.kicad_pcb]
2024-12-23 Top基板裏側のソケットを逃す穴を作成
    [SandyLPD_Plate_Mid-CNT.kicad_pcb]
2024-12-23 WIP 基板Base 右手MCUまわりを配置中
2024-12-24 右手MCUまわりの配置中
2024-12-24 WIP 右手MCUまわりを配置中
2024-12-24 リセットスイッチ穴追加。USBまわり少し拡大
    [SandyLPD_Plate_BottomB.kicad_pcb]
2024-12-24 ソケット逃し穴の形状を変更
    [SandyLPD_Plate_BottomA.kicad_pcb, SandyLPD_Plate_BottomA.kicad_sch]
2024-12-24 EC11Kサポート廃止（新規設計非推奨のため）
    [SandyLPD_Base.kicad_sch, SandyLPD_Plate_BottomA.kicad_pcb, SandyLPD_Plate_BottomA.kicad_sch]
2024-12-25 右手スピーカーの位置を調整
    [SandyLPD_Base.kicad_pcb]
2024-12-25 基板Base右手側 配線中
    [SandyLPD_Base.kicad_pcb]
2024-12-25 右手配線ほぼ完了 全体調整中
    [SandyLPD_Base.kicad_pcb]
2024-12-25 WIP 配線調整
    [SandyLPD_Base.kicad_pcb]
2024-12-25 配線ひとまず完了
    [SandyLPD_Base.kicad_pcb, SandyLPD_Base.kicad_sch]
2024-12-25 配線調整
    [SandyLPD_Base.kicad_pcb]
2024-12-25 ゴムシート貼り付け位置を準備中
    [SandyLPD_Base.kicad_pcb]
2024-12-26 ビルドガイドをユーザーズマニュアルに変えて、少しずつ書き始め。
2024-12-27 製作過程を追記中
2024-12-27 LEDをJLCPCBのBasic Partsに変更
    [SandyLPD_Base.kicad_pcb, SandyLPD_Base.kicad_sch]
2024-12-27 #32 DIPスイッチにLEDのON/OFFを接続
    [SandyLPD_Base.kicad_pcb, SandyLPD_Base.kicad_sch]
2024-12-27 シルク表示を調整
    [SandyLPD_Base.kicad_pcb, SandyLPD_Base.kicad_sch]
2025-01-01 ボトムプレートの穴を大きく
    [SandyLPD_Base.kicad_pcb, SandyLPD_Plate_BottomA.kicad_pcb, SandyLPD_Plate_BottomA.kicad_sch]
2025-01-01 電源LED位置調整。ボトムA,Bのリセット穴サイズ変更。Fusion用STEP出力。
    [SandyLPD_Base.kicad_pcb, SandyLPD_Mid-CNT.kicad_pcb, SandyLPD_Mid-ISO.kicad_pcb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]
